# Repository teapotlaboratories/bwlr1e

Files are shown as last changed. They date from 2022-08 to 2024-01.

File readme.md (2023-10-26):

# Teapotlabs BWLR1E
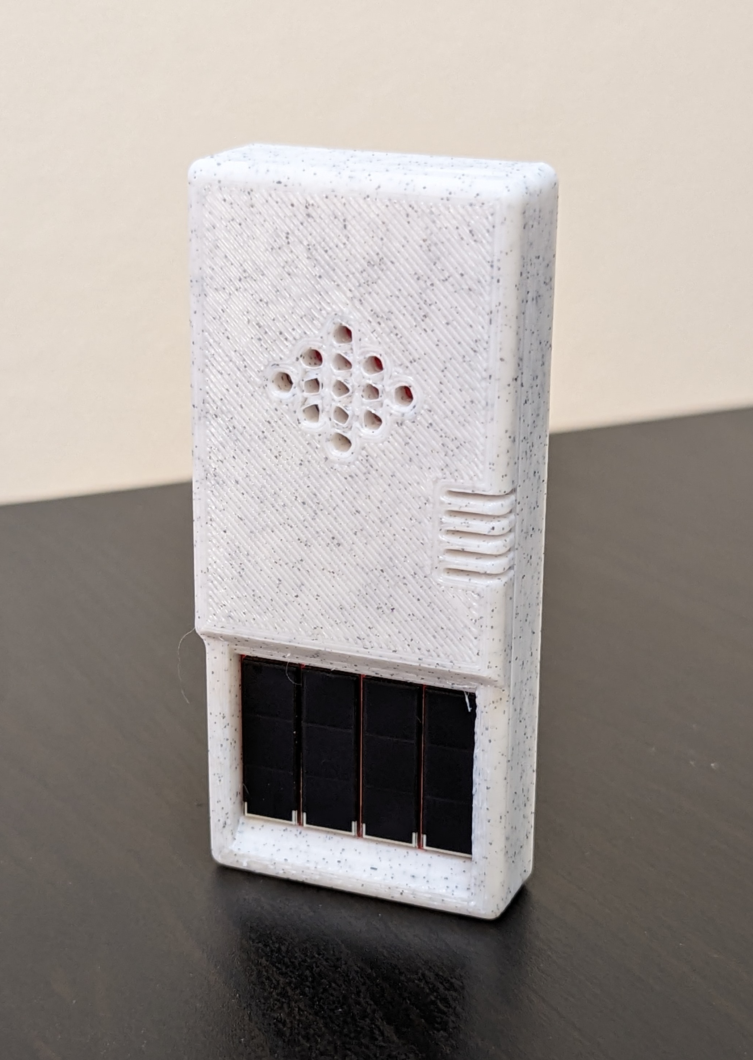
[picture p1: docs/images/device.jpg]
 
 
Teapotlabs BWLR1E is a solar-powered wireless LoRa environmental sensor capable of sensing temperature, humidity, air pressure and air quality using the on-board BME688. 
With STM32WLE MCU as it's core and AEM10941 for solar charging, the device is capable of multi-year operation with the possibility of indefinite battery-life by utilizing the solar charging capability

Teapotlabs BWLR1E is part of  [Teapot open-hardware project](https://github.com/teapotlaboratories). 
  
## Disclaimer
- The 1KM range is based on [AERQ - Air Quality Monitoring](https://www.seeedstudio.com/blog/2022/04/27/monitoring-indoor-air-pollutants-the-silent-issue-for-smart-city-iot-using-seeed-lora-e5-and-fusion-pcba/) design, but have not been tested on this device yet

## Acknowledgement
The project won't be possible without the amazing work from people across the globe. The following are the reference to those awesome projects:

 - [LoRa e5 Tiny](https://github.com/hallard/LoRa-E5-Tiny)
 - [AERQ - Air Quality Monitoring](https://www.seeedstudio.com/blog/2022/04/27/monitoring-indoor-air-pollutants-the-silent-issue-for-smart-city-iot-using-seeed-lora-e5-and-fusion-pcba/)
	 - [Github](https://github.com/Mircerson/AERQ) 
 - [TSEM](https://hackaday.io/project/159139-tiny-solar-energy-module-tsem)

## Specification

- [RAK3172](https://docs.rakwireless.com/Product-Categories/WisDuo/RAK3172-Module/Overview/): An STM32WLE5CC module
- [AEM10941](https://e-peas.com/product/aem10941): Solar energy harvesting
- 3.3V only power/pin. 
- 3uA Deep-Sleep
- BME688 for Environmental Sensing
- Switchable TX Power. 14 dBm(50mA) or 22 dBm(140mA) ( on 915MHz frequency )
- Supports LoRaWAN 1.0.3
- 1KM+ Range
- UART2 breakout for **Arduino/Mbed OS/STM32Cube** programming 
- SWD breakout for debugging and programming
- iPEX antenna connector 
- 3.7 Volts LiPo Battery

## Schematics

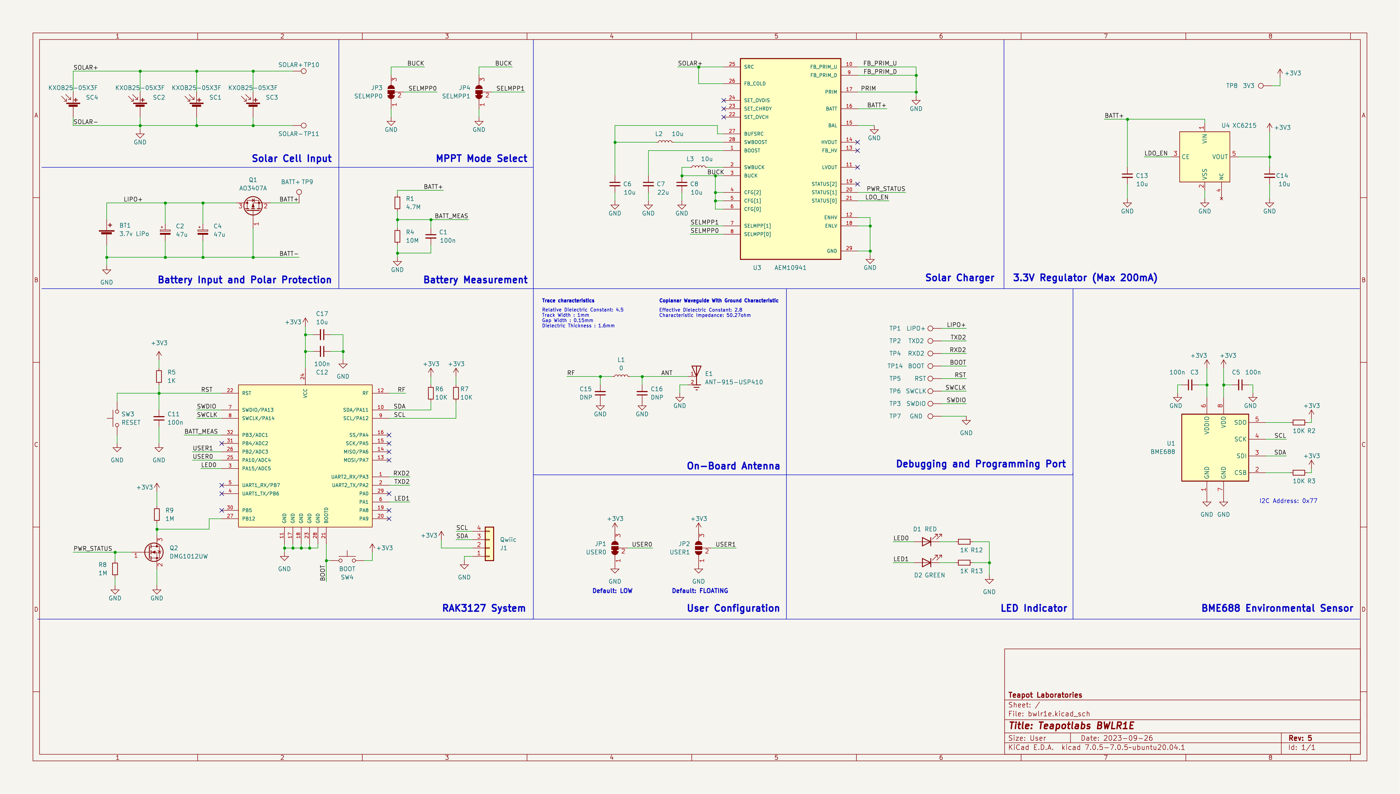
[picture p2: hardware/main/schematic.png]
schematic


## Boards
 <p align="center">  pcb_render<br><b>PCB Render</b></p>

Built using KiCAD, the board is design to be as small as possible with all components placed on the top side of the PCB.
The following are the lists of revision of the board:
- Revision 1: Initial design
- Revision 2: Better trace, use rounded trace and change solar cell wiring to parallel for all cell
- Revision 3: Rename 3V3 to PRIMIN and breaks out PRIMIN
- Revision 4: Improve layout and wiring, and add Qwiic connector
- Revision 5: Change C6 to 22uF

The following design are based on the latest revision.
| Top Board | Bottom Board |
|--|--|
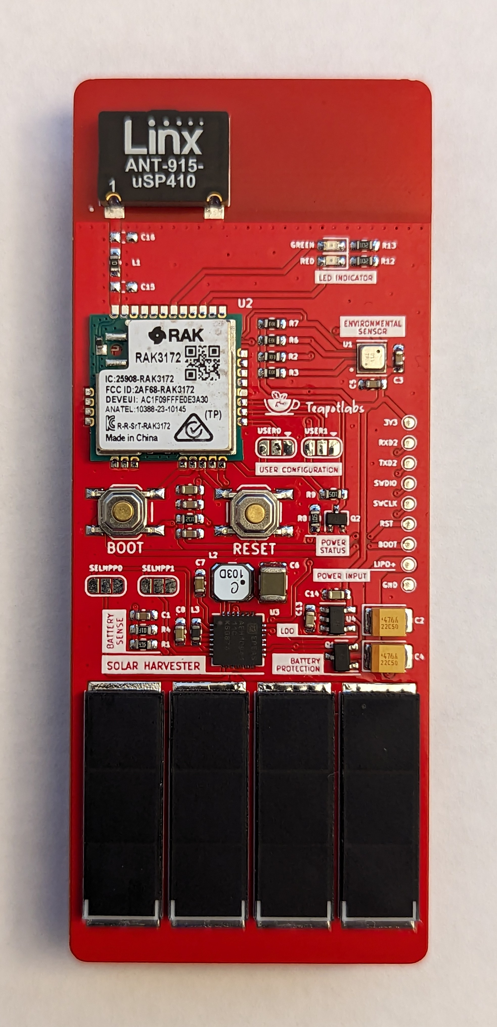
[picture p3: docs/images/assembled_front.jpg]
assembled_front
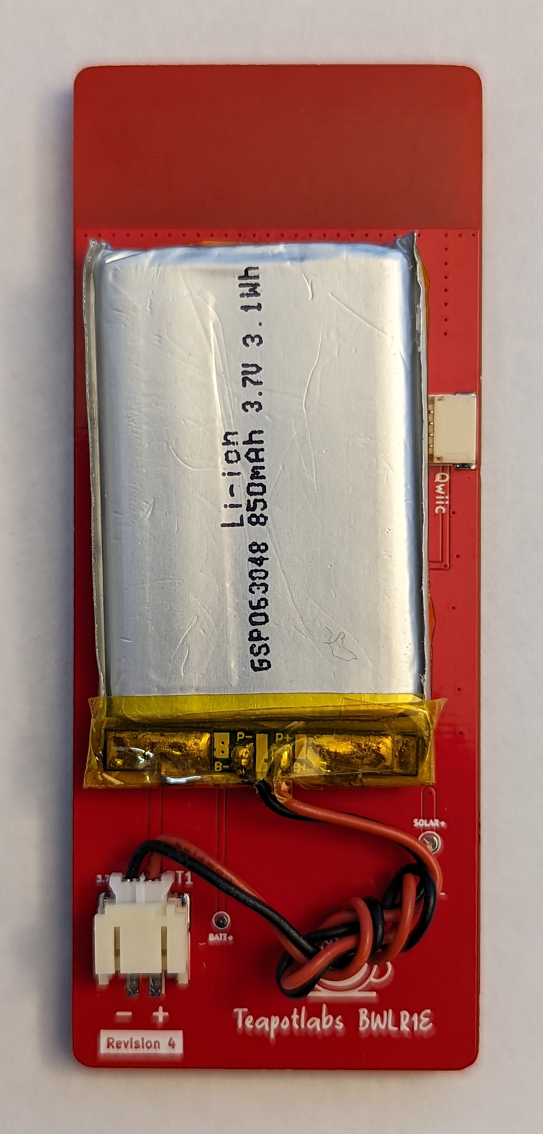
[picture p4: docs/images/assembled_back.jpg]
assembled_back
|  |  |
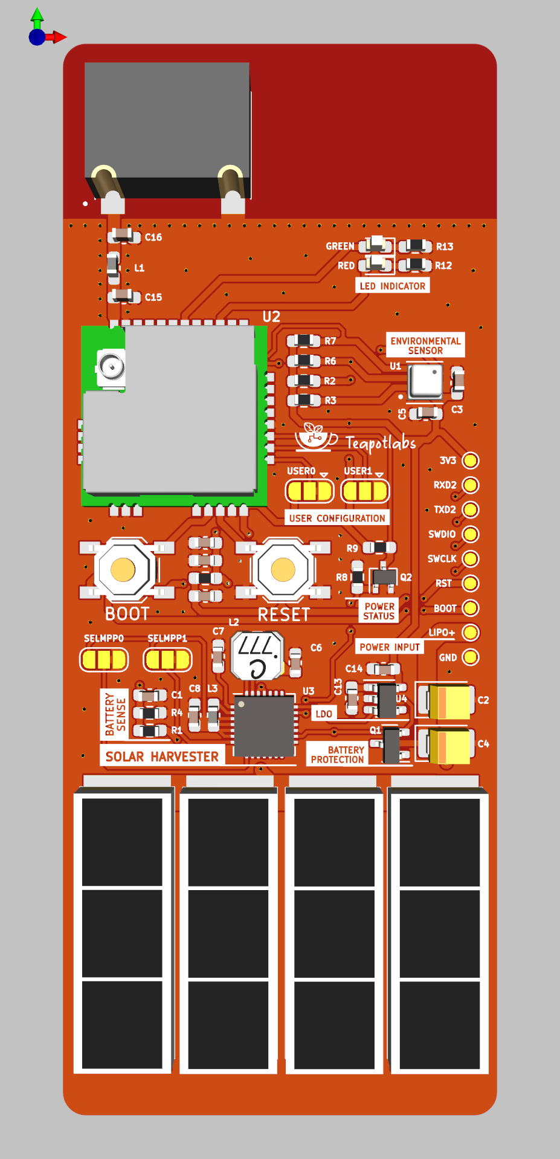
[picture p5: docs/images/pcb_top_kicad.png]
pcb_front
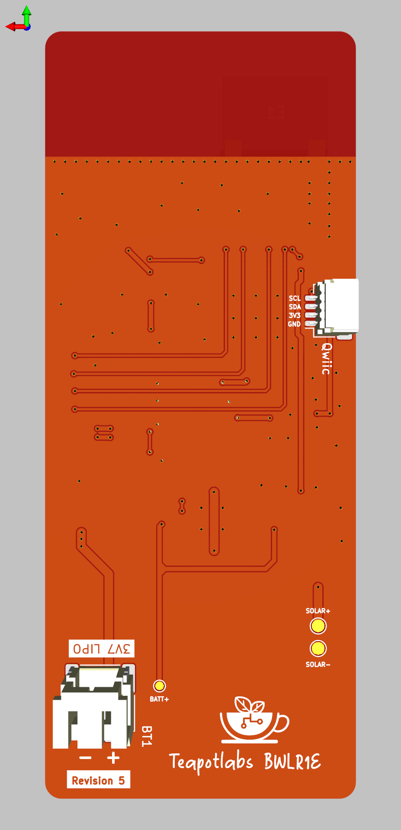
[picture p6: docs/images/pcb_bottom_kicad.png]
pcb_bottom
|  |  |

 <p align="center"> pcb<br><b>PCB Top and Bottom Layout</b></p> 
  
### Case
<p align="center">  case_render</p>

Built using [TinkerCAD](https://www.tinkercad.com). The case are 3D printable with any generic 3D printer with/without support. The STL files are available [here](https://github.com/teapotlaboratories/bwlr1e/tree/main/hardware/main/case)
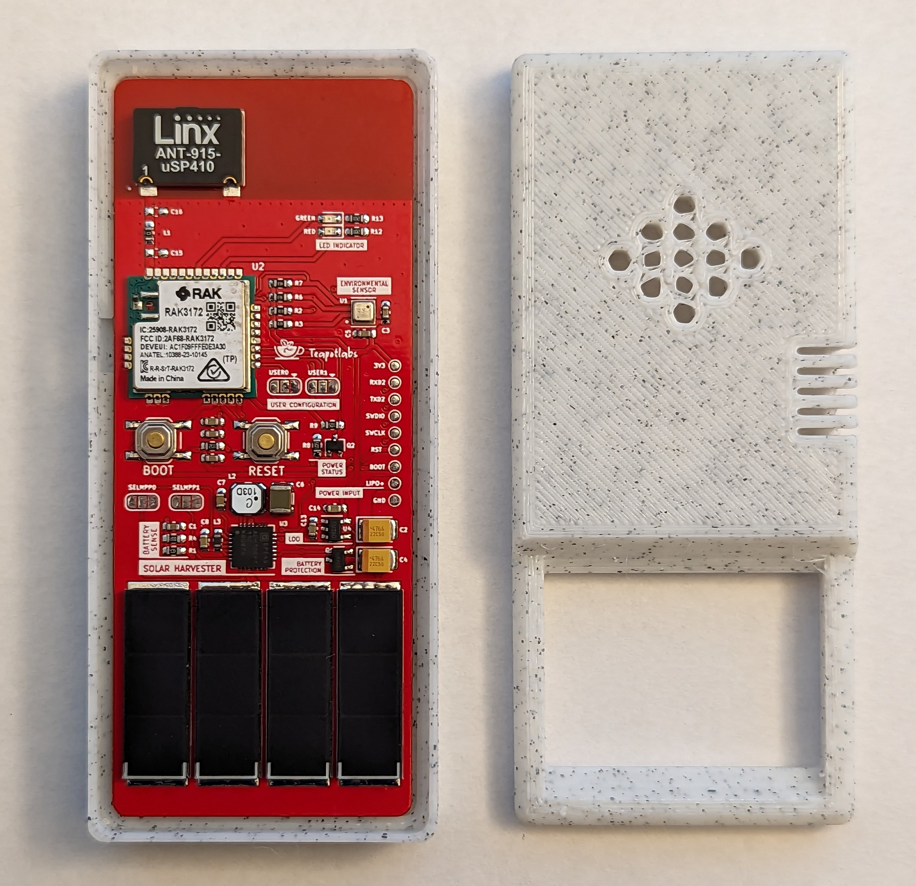
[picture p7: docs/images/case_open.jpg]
 <p align="center"><br><b>Case Open</b></p>

For adding additional sensors, Qwiic connector is also available on the left side of the board.
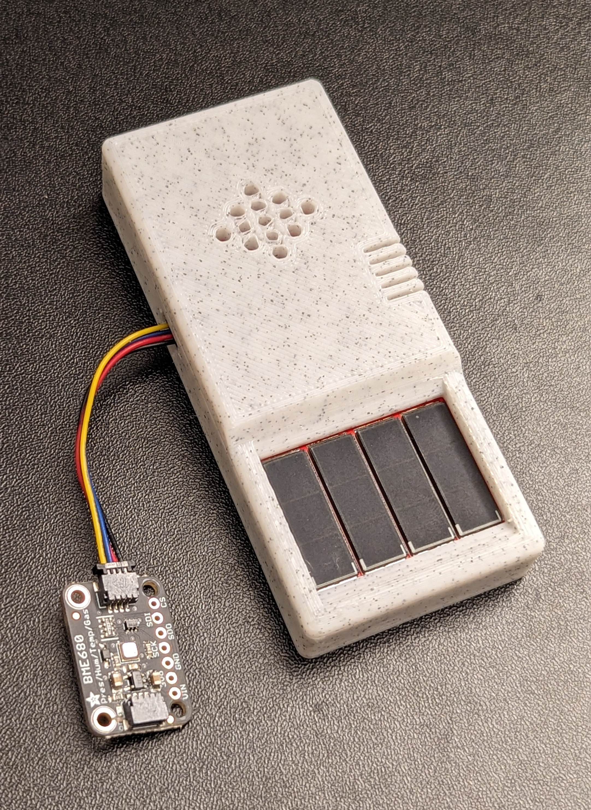
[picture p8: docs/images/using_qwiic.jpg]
 <p align="center"><br><b>Connecting to Adafruit BME688</b></p>

The case is design to be as small as possible with an additional magnets in the back to ease the placement of the sensor. The following are the list of material used at the time of testing:
- 3.7v LiPo Battery, 850mAh 6mm x 30mm x 48mm
- 4 piece of 8mm x 2mm neodymium magnet

<p align="center">placement_showcase<br><b>Sensor Placement with Magnet</b></p>

### Measurement
Power consumption and solar charging current are measured using [Nordic PPK2](https://www.nordicsemi.com/Products/Development-hardware/Power-Profiler-Kit-2)  and [CurrentRanger](https://lowpowerlab.com/shop/product/152).
The following are the summary of the measurement:
- Transmit 14dBm:  305ms @ 20mA
- Deep-Sleep : 3.22 uA
- Direct Sunlight Solar Charge: 9mA
- Indirect Sunlight Solar Charge: 300uA

> :warning: **Tested on Revision 3, but should be similar to Revision 5** 

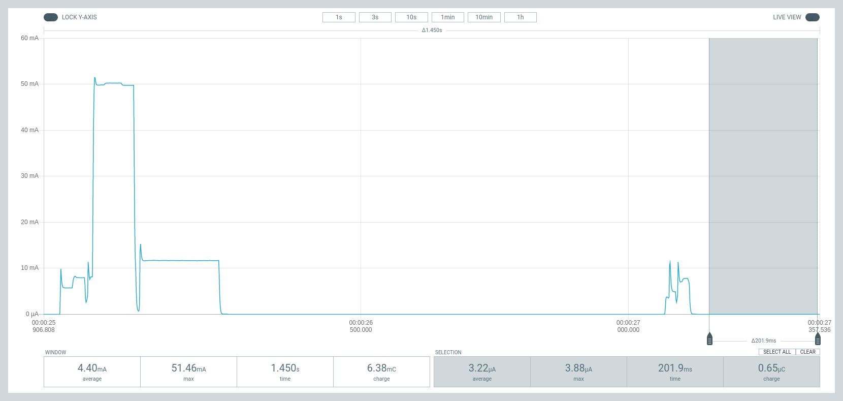
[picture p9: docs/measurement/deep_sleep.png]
deep_sleep
<p align="center"><br><b>Deep-Sleep</b></p>

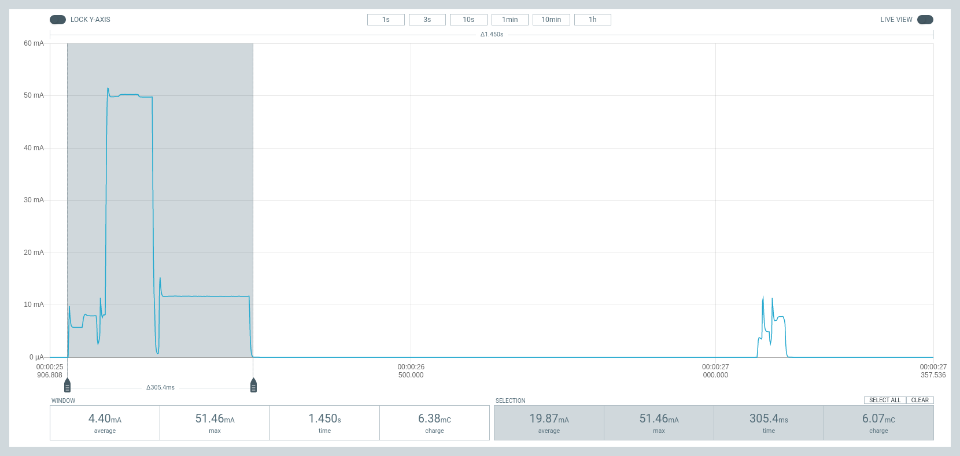
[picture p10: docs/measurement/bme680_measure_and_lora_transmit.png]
bme688_measure_and_lora_transmit
<p align="center"><br><b>BME688 Measure and LoRa Transmit</b></p>

| Solar Charge - Direct Sunlight | Solar Charge - Indirect Sunlight |
|--|--|
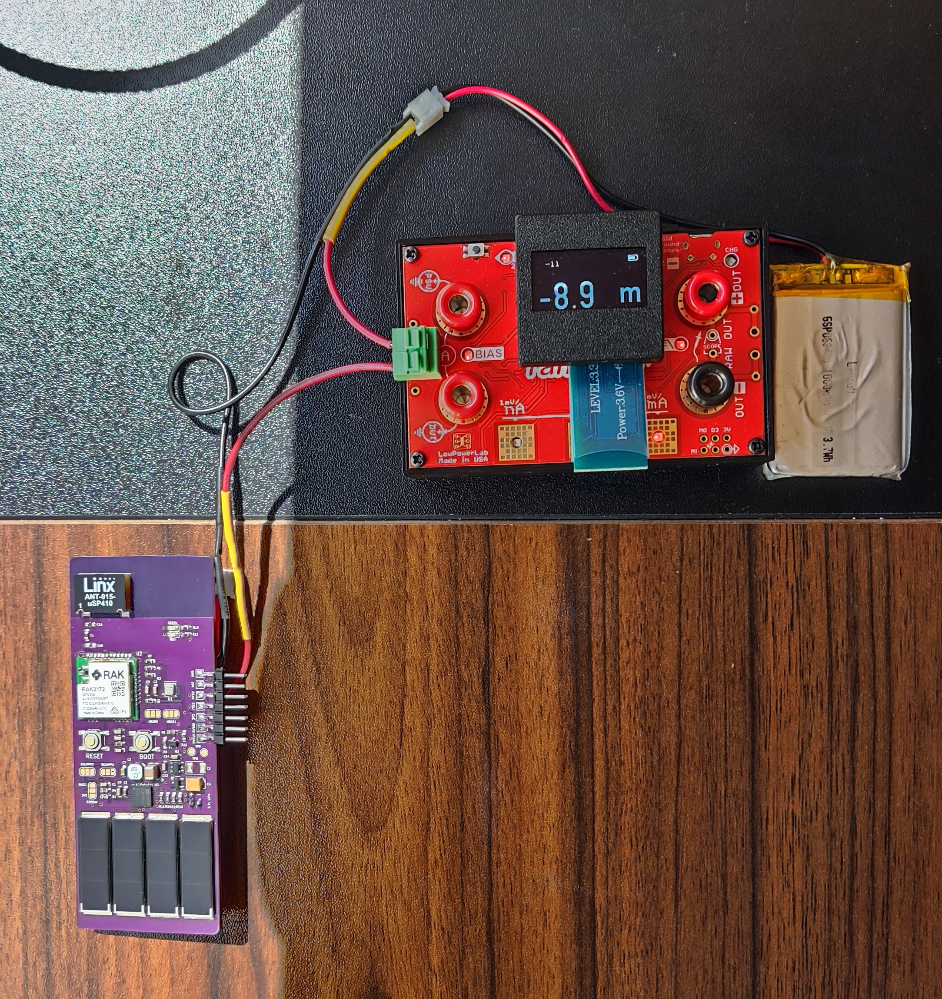
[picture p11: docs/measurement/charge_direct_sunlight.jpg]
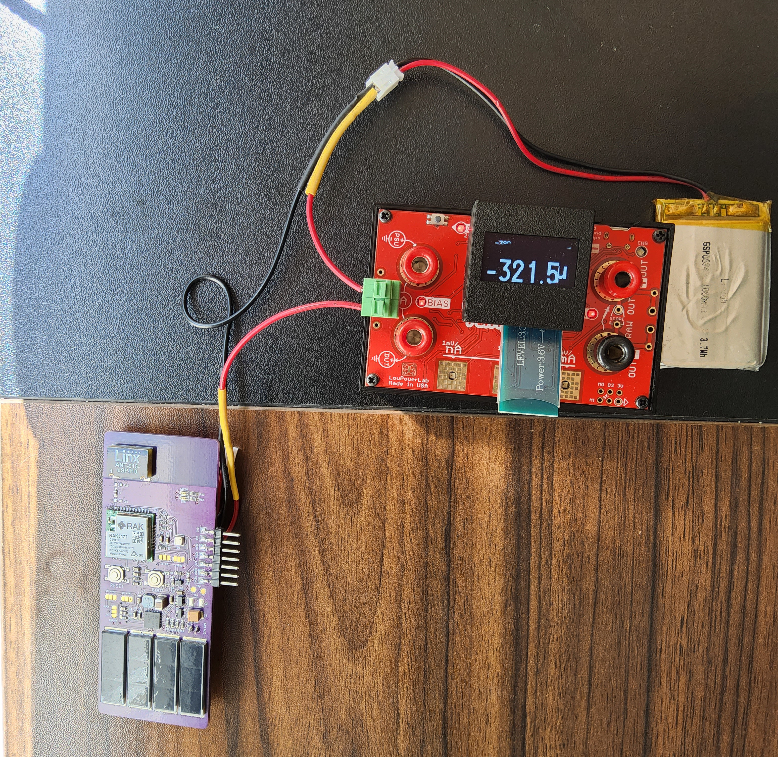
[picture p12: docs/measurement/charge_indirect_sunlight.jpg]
|  |  |

More measurement can be found [here](https://github.com/teapotlaboratories/bwlr1e/tree/main/docs/measurement)

### Bill Of Materials
Most of the components are generic and can be bought from any electornics/semi-conductor distributor. RAK3172 is the only component available in [RAKwireless store](https://store.rakwireless.com/products/wisduo-lpwan-module-rak3172?variant=40014759493830). The bill of materials can be downloaded [here](https://github.com/teapotlaboratories/bwlr1e/blob/main/hardware/main/bill_of_materials.csv)

> :warning: **Be sure to buy the RAK3172 variant without IPEX to use the On-Board Antenna** 

## Programming

> :warning: **Board can only be powered when LiPo battery is connected** 

Programming the device can be done over the **UART2** or **SWD**, available on the right side of the board or uses the [BWLR1E Programmer](https://github.com/teapotlaboratories/bwlr1e/blob/main/readme_programmer.md).
Out of the factory, the RAK3172 chip ships with an **AT firmware** that can be tested by connecting a USB-to-UART bridge to the **UART2** port.

The following are some very good tutorial to start developing with the device:

- [Communicating with the AT firmware](https://docs.rakwireless.com/Product-Categories/WisDuo/RAK3172-Module/Quickstart/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)
 - [Programming with Arduino](https://docs.rakwireless.com/Product-Categories/WisDuo/RAK3172-Module/Quickstart/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)
 - [Programming with STM32Cube](https://docs.rakwireless.com/Product-Categories/WisDuo/RAK3172-Module/Low-Level-Development/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)
 - [Programming with MbedOS](https://github.com/hallard/LoRa-E5-Tiny/blob/main/README.md#compile-and-flash-firmware)

For connecting to the **UART2** port, use any USB-to-UART bridge module. In testing, the [Sparkfun](https://www.sparkfun.com/products/14050) board is used for communication with AT firmware and programming over **Arduino**.
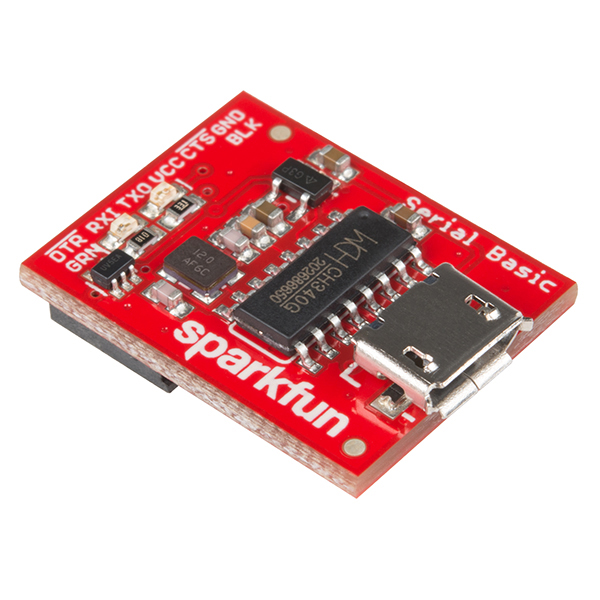
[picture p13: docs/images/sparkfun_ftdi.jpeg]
 <p align="center"> <br>Sparkfun USB-to-UART Bridge</p>

> :warning: **Be sure to only use 3.3V module. Do not 5V module** 

### Available SDK
Through **UART2**, user can program the device using the following SDK:
- [Arduino RUI3 SDK](https://github.com/RAKWireless/RAKwireless-Arduino-BSP-Index)
- [Arduino STM32duino SDK](https://github.com/stm32duino/Arduino_Core_STM32)
- [MbedOS](https://github.com/hallard/LoRa-E5-Tiny/blob/main/README.md#compile-and-flash-firmware)
- [STM32Cube](https://docs.rakwireless.com/Product-Categories/WisDuo/RAK3172-Module/Low-Level-Development/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)

Other than [Arduino RUI3 SDK](https://github.com/RAKWireless/RAKwireless-Arduino-BSP-Index), to program the device, user need to put the device in Serial Bootloader mode by,
1. Press and Hold `BOOT` and `RESET` button
2. Release `RESET` button 
3. Wait few seconds ( try 2 seconds )
4. Release `BOOT` button
5. Device should be in Serial Bootloader mode.

You can also use [STM32CubeProgrammer](https://www.st.com/en/development-tools/stm32cubeprog.html) , instead of the SDK  to upload a firmware
  
### Programming with Teapotlabs BWLR1E Programmer
 <p align="center"> <br>Teapotlabs BWLR1E Programmer</p>

An alternative to solder-free programming is to use the Teapotlabs BWLR1E Programmer. A full detail of the device can be found [here](https://github.com/teapotlaboratories/bwlr1e/blob/main/readme_programmer.md).
The programmer connects to UART2 of the device. 

## License
The product is open-source! However, some part of library used under **src**, might have it's own license.
Please reach out or create a ticket to report any license violation.



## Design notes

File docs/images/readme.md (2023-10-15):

# Documentation Images

## Assembled Front and Back


## Case Close
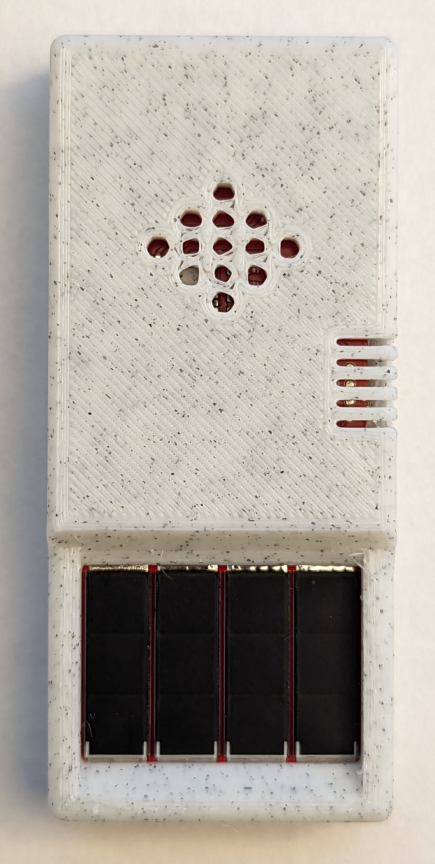
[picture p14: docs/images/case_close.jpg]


## Case Open


## Case Render


## Device


## Device Close-up
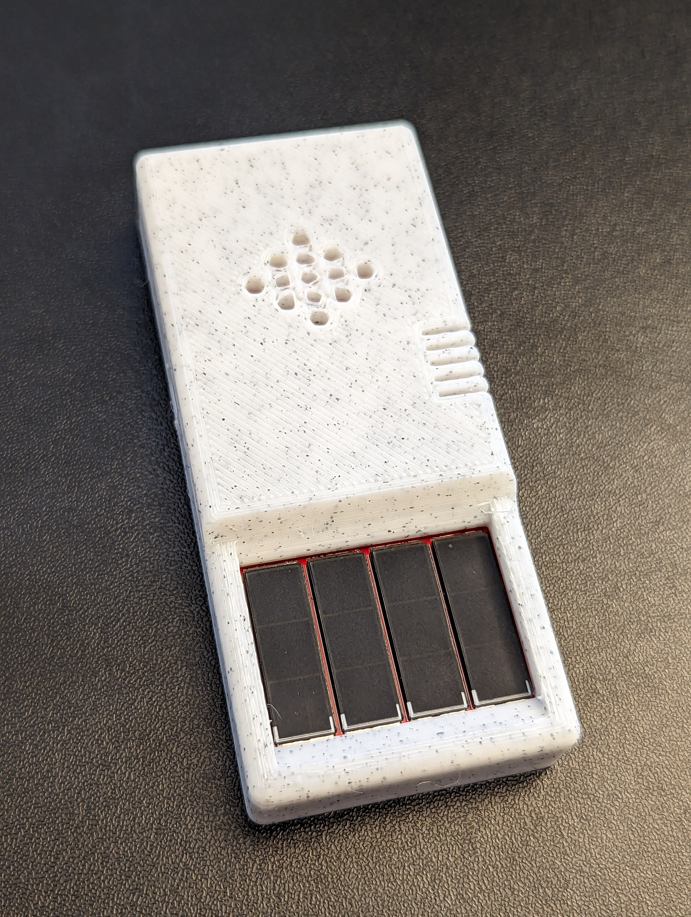
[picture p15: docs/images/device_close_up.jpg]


## PCB Render


## PCB Bottom
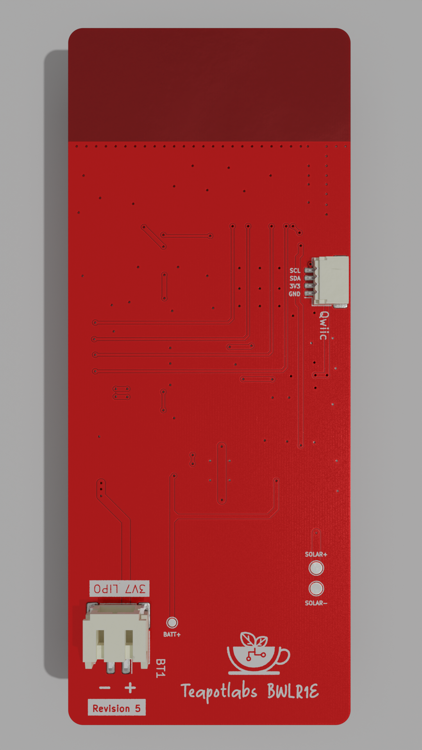
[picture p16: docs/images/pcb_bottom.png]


## PCB Top
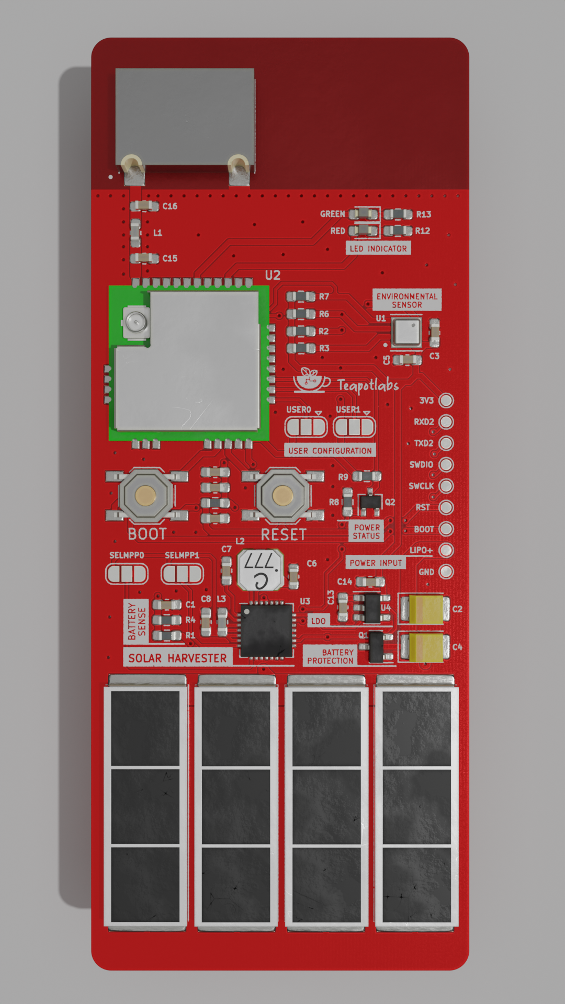
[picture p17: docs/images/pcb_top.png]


## Case Open


## Case Open


## Placement Showcase


## AA Battery for Comparison
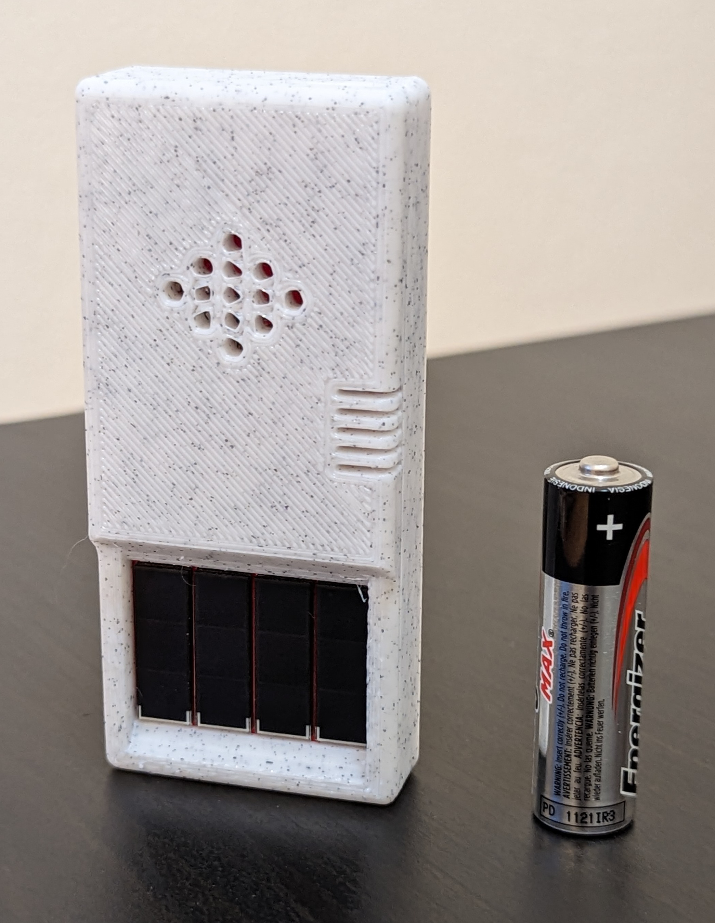
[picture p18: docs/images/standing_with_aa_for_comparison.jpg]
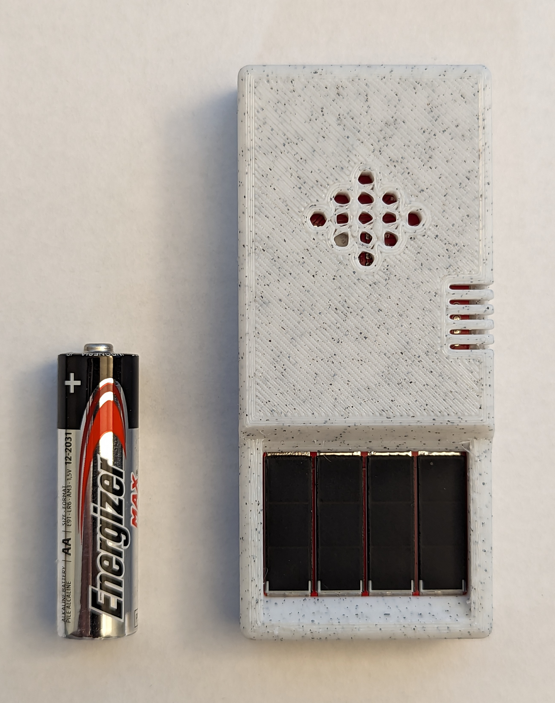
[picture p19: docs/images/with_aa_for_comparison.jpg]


## Using Qwiic Connector


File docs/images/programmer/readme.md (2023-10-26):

# Documentation Images

## Assembled Front and Back
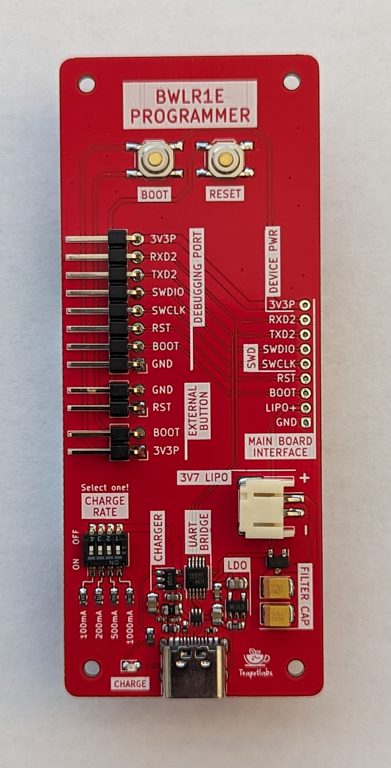
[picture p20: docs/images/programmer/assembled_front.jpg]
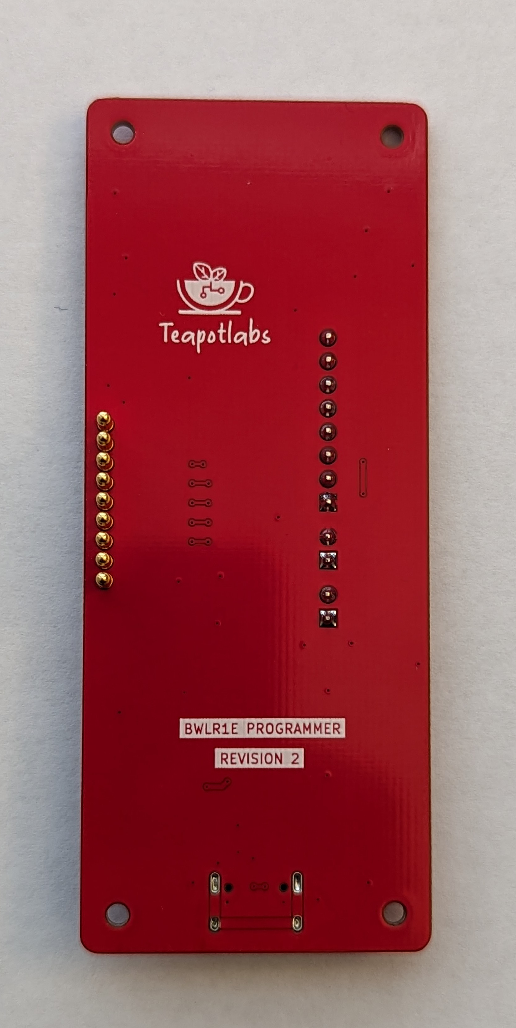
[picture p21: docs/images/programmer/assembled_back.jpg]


## Case Close
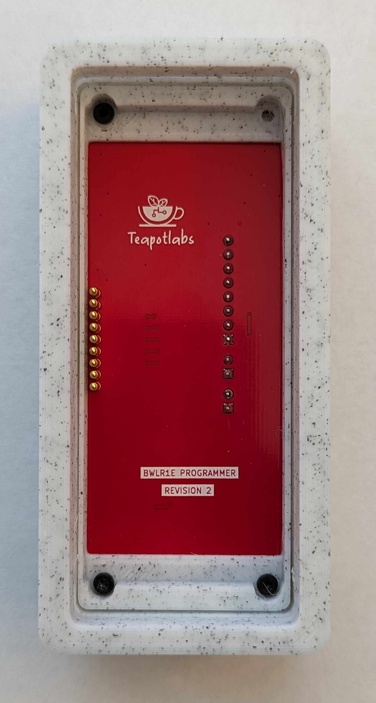
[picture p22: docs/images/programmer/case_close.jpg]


## Case Open
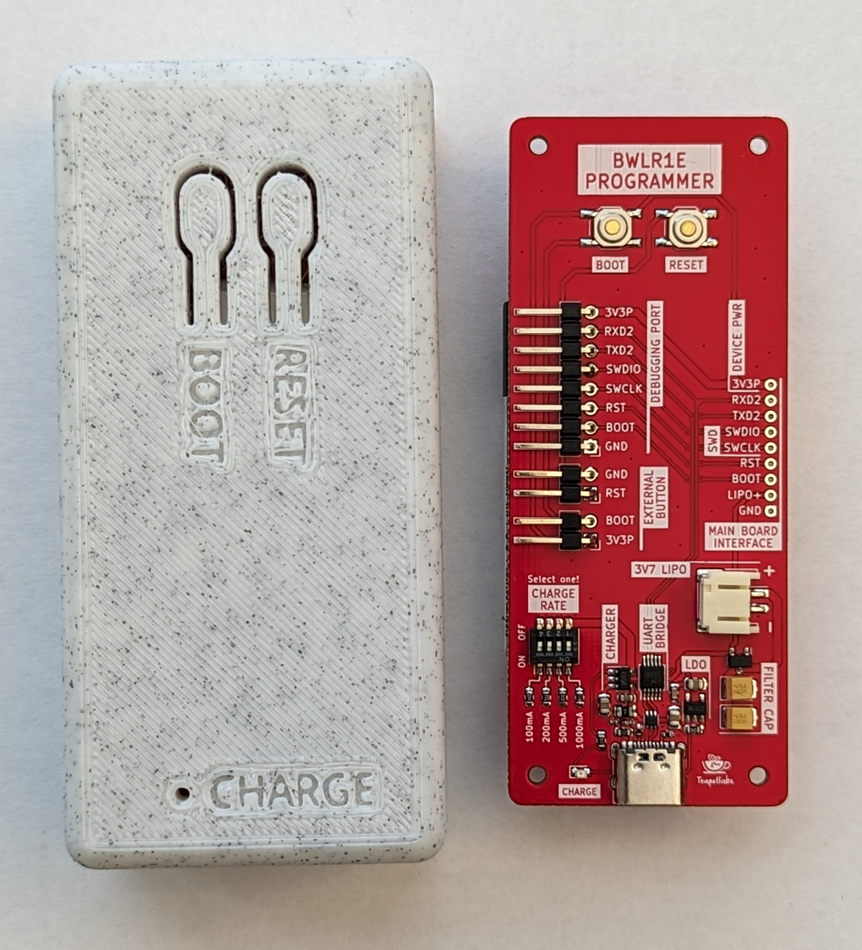
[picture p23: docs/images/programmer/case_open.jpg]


## Case Render


## Device
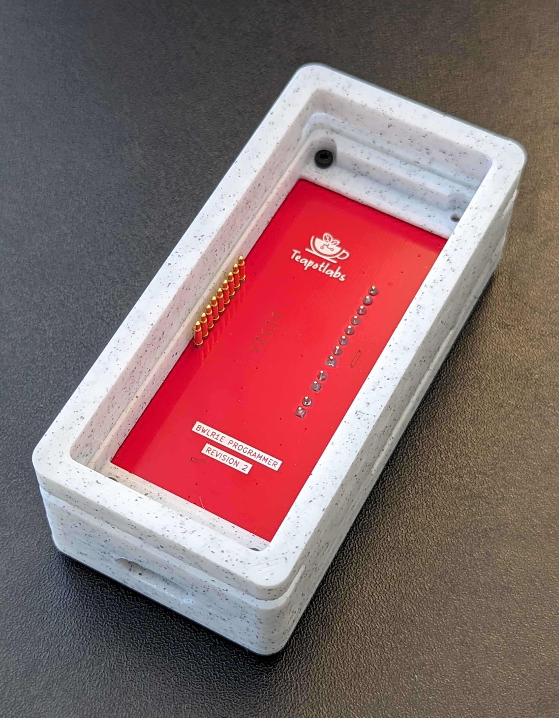
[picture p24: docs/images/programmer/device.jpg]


## PCB Render


## PCB Bottom
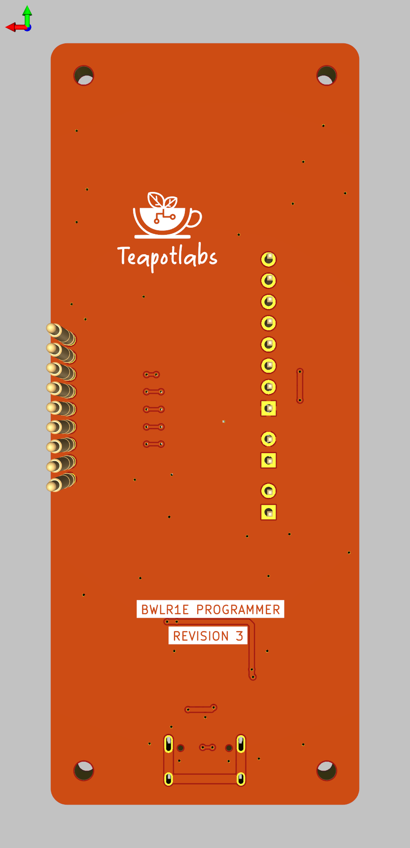
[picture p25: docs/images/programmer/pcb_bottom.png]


## PCB Top
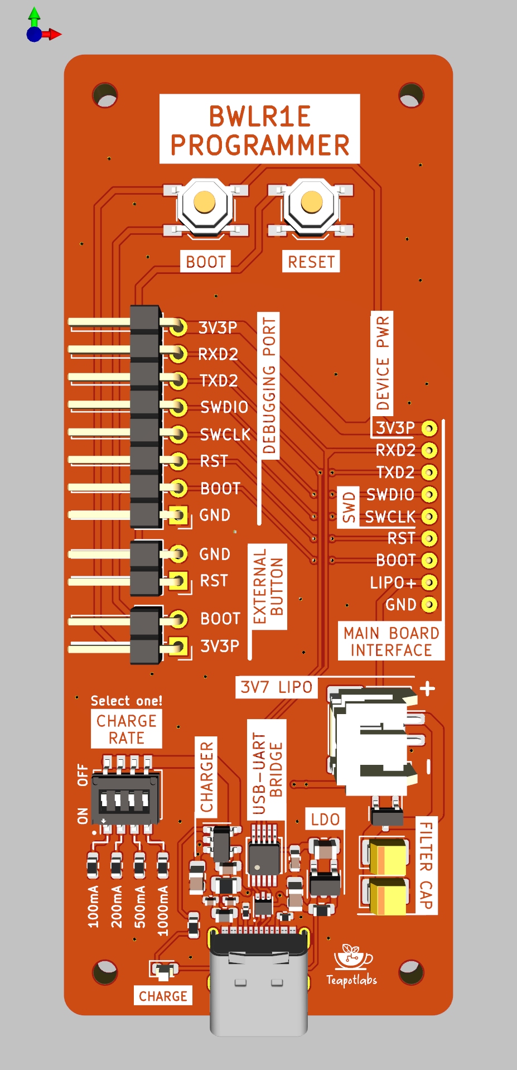
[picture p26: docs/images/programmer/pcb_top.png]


## Programming BWLR1E


## Showcase Render Exploded View
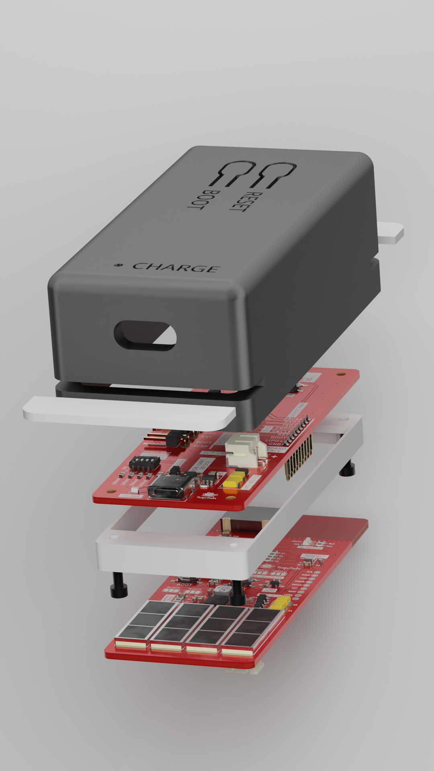
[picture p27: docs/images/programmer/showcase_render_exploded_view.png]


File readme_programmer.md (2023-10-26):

# Teapotlabs BWLR1E Programmer	

<p align="center">  case_render</p>
 
Teapotlabs BWLR1E Programmer is a device to support programming Teapotlabs BWLR1E without soldering to the device. The programmer interface to the device program pad via pogo-pins.
 
## Specification

- CH340E USB to UART Bridge for Teapotlabs BWLR1E Programming
- 1A Charge rate to Teapotlabs BWLR1E battery
- Pogo-pin to interface to Teapotlabs BWLR1E. Connects the following pin:
	- RXD2
	- TXD2
	- SWDIO
	- SWCLK
	- RST
	- BOOT
	- LIPO+
- On-board `boot` and `reset` button
- Pin header for external button

## Schematics

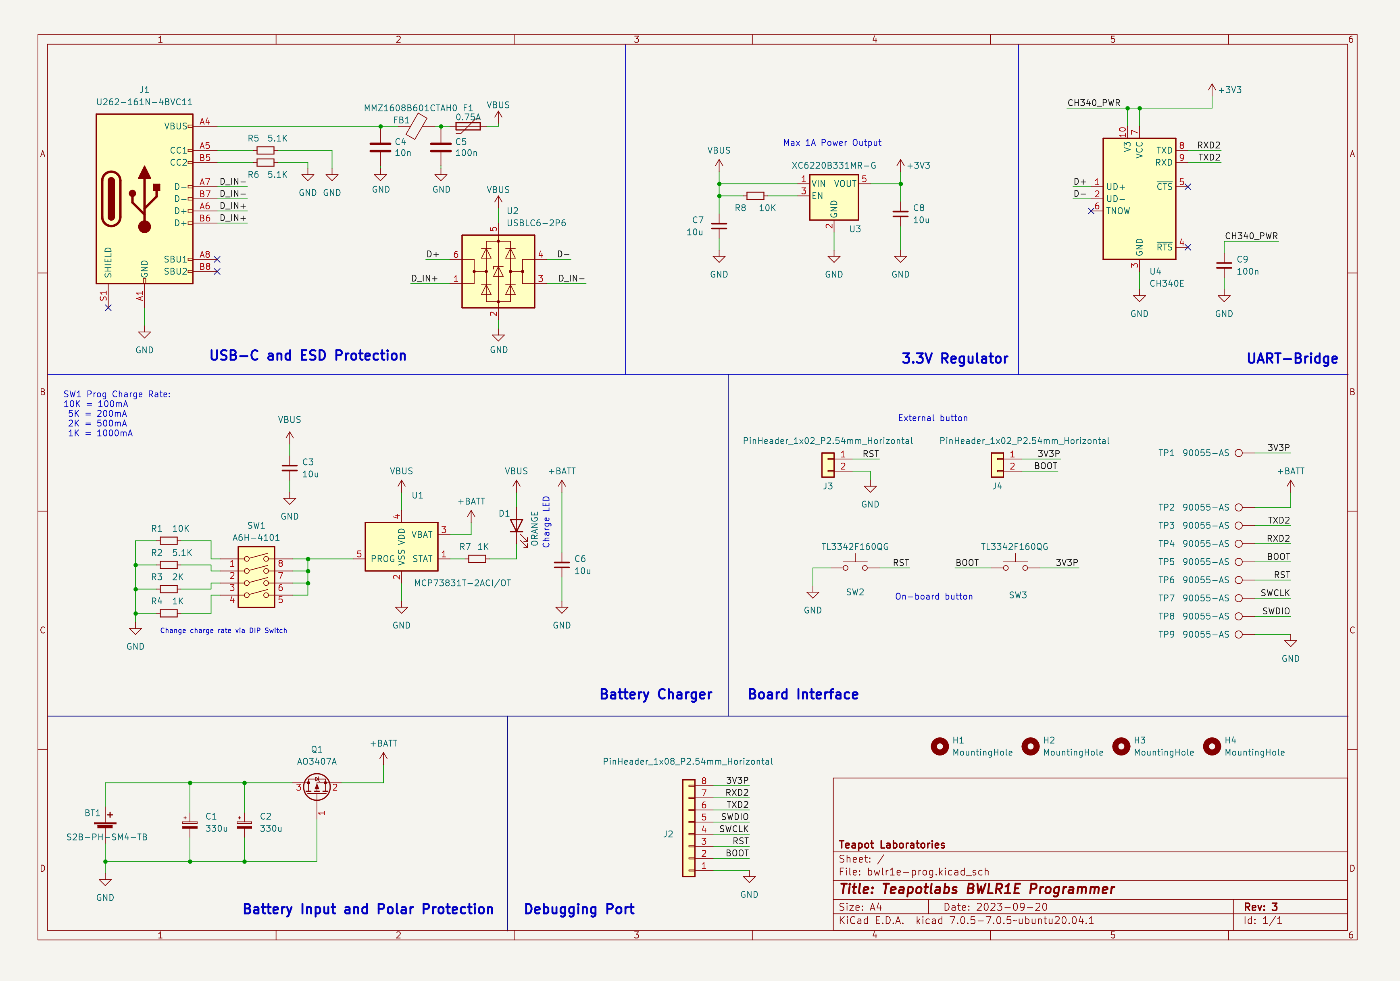
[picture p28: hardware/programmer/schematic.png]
schematic


## Boards
 <p align="center">  pcb_render<br><b>PCB Render</b></p>

Built using KiCAD v7, the board is design to connect to the programming and charge pad of Teapotlabs BWLR1E via pogo-pins connector

The following design are based on the latest revision.
| Top Board | Bottom Board |
|--|--|
| <p align="center"> assembled_front</p> | <p align="center"> assembled_back</p> |
| <p align="center"> pcb_front</p> | <p align="center"> pcb_bottom</p> |

 <p align="center"> pcb<br><b>PCB Top and Bottom Layout</b></p> 
  
### Case
 <p align="center"> <br>Teapotlabs BWLR1E Programmer Exploded View</p>

Built using [TinkerCAD](https://www.tinkercad.com). The case are 3D printable with any generic 3D printer with/without support. The STL files are available [here](https://github.com/teapotlaboratories/bwlr1e/tree/main/hardware/programmer/case)
The case is made of 3 parts:
- Main case: holds the Programmer.
- Separator: separate the programmer and Teapotlabs BWLR1E.
- Locks: locks Teapotlabs BWLR1E in place for charging the device.
 <p align="center"><br><b>Case Open</b></p>

### Bill Of Materials
Most of the components are generic and can be bought from any electornics/semi-conductor distributor. The bill of materials can be downloaded [here](https://github.com/teapotlaboratories/bwlr1e/blob/main/hardware/programmer/bill_of_materials.csv)

## Programming Teapotlabs BWLR1E

 <p align="center"> <br>Setting-up Teapotlabs BWLR1E Programmer</p>
 
Using the programmer, Teapotlabs BWLR1E can be programmed via the USB-C available in the programmer.
Out of the factory, the Teapotlabs BWLR1E chip ships with an **AT firmware** that can be tested by sending AT commands using the programmer USB-C.

The following are some very good tutorial to start developing with the device:

- [Communicating with the AT firmware](https://docs.rakwireless.com/Product-Categories/WisDuo/RAK3172-Module/Quickstart/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)
 - [Programming with Arduino](https://docs.rakwireless.com/Product-Categories/WisDuo/RAK3172-Module/Quickstart/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)
 - [Programming with STM32Cube](https://docs.rakwireless.com/Product-Categories/WisDuo/RAK3172-Module/Low-Level-Development/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)
 - [Programming with MbedOS](https://github.com/hallard/LoRa-E5-Tiny/blob/main/README.md#compile-and-flash-firmware)

### Available SDK
Through the USB-C, user can program Teapotlabs BWLR1E using the following SDK:

-   [Arduino RUI3 SDK](https://github.com/RAKWireless/RAKwireless-Arduino-BSP-Index)
-   [Arduino STM32duino SDK](https://github.com/stm32duino/Arduino_Core_STM32)
-   [MbedOS](https://github.com/hallard/LoRa-E5-Tiny/blob/main/README.md#compile-and-flash-firmware)
-   [STM32Cube](https://docs.rakwireless.com/Product-Categories/WisDuo/RAK3172-Module/Low-Level-Development/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)

Other than  [Arduino RUI3 SDK](https://github.com/RAKWireless/RAKwireless-Arduino-BSP-Index), to program the device, user need to put the device in Serial Bootloader mode by,

1.  Press and Hold  `BOOT`  and  `RESET`  button
2.  Release  `RESET`  button
3.  Wait few seconds ( try 2 seconds )
4.  Release  `BOOT`  button
5.  Device should be in Serial Bootloader mode.

You can also use  [STM32CubeProgrammer](https://www.st.com/en/development-tools/stm32cubeprog.html)  , instead of the SDK to upload a firmware

## License
The product is open-source! However, some part of library used under **src**, might have it's own license.
Please reach out or create a ticket to report any license violation.



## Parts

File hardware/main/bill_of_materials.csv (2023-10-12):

Id | Designator | Quantity | Manufacturer | Manufacturer Part Number | Value | Description | Footprint | Type | Distributor | Distributor Part Number | Distributor Link
1 | BT1 | 1 | JST | S2B-PH-SM4-TB | 3.7v LiPo | Connector Header Right Angle 2 position 0.079" (2.00mm) | JST_PH_S2B-PH-SM4-TB | SMD | LCSC | C295747 | https://www.lcsc.com/product-detail/Wire-To-Board-Wire-To-Wire-Connector_JST-Sales-America-S2B-PH-SM4-TB-LF-SN_C295747.html
2 | C1, C3, C5, C11, C12 | 5 | YAGEO | CC0603KRX7R6BB104 | 100n | Ceramic Capacitor 100nF 10% 10V X7R | C_0603_1608Metric | SMD | LCSC | C519438 | https://www.lcsc.com/product-detail/Multilayer-Ceramic-Capacitors-MLCC-SMD-SMT_YAGEO-CC0603KRX7R6BB104_C519438.html
3 | C2, C4 | 2 | KYOCERA AVX | TPSB476K010R0350 | 47u | Tantalum Capacitors 47µF 10% 10 V 250mOhm | EIA-3528-15 | SMD | Digikey | 478-9088-1-ND | https://www.digikey.com/en/products/detail/kyocera-avx/TPSB476K010R0350/1472821
4 | C7 | 1 | Murata Electronics | GRM188R61A226ME15D | 22u | Ceramic Capacitor 22uF 20% 10V X5R | C_0603_1608Metric | SMD | LCSC | C84419 | https://www.lcsc.com/product-detail/Multilayer-Ceramic-Capacitors-MLCC-SMD-SMT_Murata-Electronics-GRM188R61A226ME15D_C84419.html
5 | C6, C8, C13, C14, C17 | 5 | Murata Electronics | GRT188R61A106KE13D | 10u | Ceramic Capacitor 10uF 10% 10V X5R | C_0603_1608Metric | SMD | LCSC | C782172 | https://www.lcsc.com/product-detail/Multilayer-Ceramic-Capacitors-MLCC-SMD-SMT_Murata-Electronics-GRT188R61A106KE13D_C782172.html
6 | D1 | 1 | Lite-On | LTST-C191KRKT | RED | Red 2V 20mA | LED_0603_1608Metric | SMD | LCSC | C125099 | https://www.lcsc.com/product-detail/Light-Emitting-Diodes-LED_Lite-On-LTST-C191KRKT_C125099.html
7 | D2 | 1 | Lite-On | LTST-C190KGKT | GREEN | Green 2V 20mA | LED_0603_1608Metric | SMD | LCSC | C125094 | https://www.lcsc.com/product-detail/Light-Emitting-Diodes-LED_Lite-On-LTST-C190KGKT_C125094.html
8 | E1 | 1 | Linx Technologies Inc. | ANT-915-USP410 | ANT-915-USP410 | Chip RF Antenna 902MHz ~ 930MHz 0.9dBi Solder Surface Mount | ANT-915-USP410 | SMD | Digikey | 343-ANT-915-USP410CT-ND | https://www.digikey.com/en/products/detail/linx-technologies-inc/ANT-915-USP410/13165344
9 | J1 | 1 | JST | SM04B-SRSS-TB | Qwiic | Connector Header Right Angle 4 position 0.039" (1.00mm) | JST_SH_SM04B-SRSS-TB | SMD | LCSC | C160404 | https://www.lcsc.com/product-detail/Wire-To-Board-Wire-To-Wire-Connector_JST-Sales-America-SM04B-SRSS-TB-LF-SN_C160404.html
10 | L1 | 1 | UNI-ROYAL(Uniroyal Elec) | 0603WAF0000T5E | 0 | Resistor 0 5% 100mW | L_0603_1608Metric | SMD | LCSC | C21189 | https://www.lcsc.com/product-detail/Chip-Resistor-Surface-Mount_UNI-ROYAL-Uniroyal-Elec-0603WAF0000T5E_C21189.html
11 | L2 | 1 | Coilcraft | LPS4012-103MRC | 10u | Power Inductor 10uH 20% 1.1A | IND_LPS4012-103MRB | SMD | Mouser | 994-LPS4012-103MRC | https://www.mouser.com/ProductDetail/994-LPS4012-103MRC
12 | L3 | 1 | TDK | MLZ1608M100WT000 | 10u | Power Inductor 10uH 20% 90mA | L_0603_1608Metric | SMD | LCSC | C76798 | https://www.lcsc.com/product-detail/Inductors-SMD_TDK-MLZ1608M100WT000_C76798.html
13 | Q1 | 1 | Alpha & Omega Semicon | AO3407A | AO3407A | P-Channel Enhacnement Mode MOSFET 30V 4.3A 48mΩ@10V | SOT-23 | SMD | LCSC | C15155 | https://www.lcsc.com/product-detail/MOSFETs_Alpha-Omega-Semicon-AO3407A_C15155.html
14 | Q2 | 1 | TECH PUBLIC | DMG1012UW | DMG1012UW | N-Channel Enhancement Mode MOSFET 20V 0.9A 300mΩ@2.5V | SOT-323_SC-70 | SMD | LCSC | C2940609 | https://www.lcsc.com/product-detail/MOSFETs_TECH-PUBLIC-DMG1012UW_C2940609.html
15 | R1 | 1 | UNI-ROYAL(Uniroyal Elec) | 0603WAF4704T5E | 4.7M | Resistor 4.7M 1% 100mW | R_0603_1608Metric | SMD | LCSC | C23163 | https://www.lcsc.com/product-detail/Chip-span-style-background-color-ff0-Resistor-span-Surface-Mount_UNI-ROYAL-Uniroyal-Elec-0603WAF4704T5E_C23163.html
16 | R2, R3, R6, R7 | 4 | YAGEO | RC0603JR-0710KL | 10K | Resistor 10K 5% 100mW | R_0603_1608Metric | SMD | LCSC | C99198 | https://www.lcsc.com/product-detail/_YAGEO-_C99198.html
17 | R4 | 1 | UNI-ROYAL(Uniroyal Elec) | 0603WAF1005T5E | 10M | Resistor 10M 1% 100mW | R_0603_1608Metric | SMD | LCSC | C7250 | https://www.lcsc.com/product-detail/Chip-span-style-background-color-ff0-Resistor-span-Surface-Mount_UNI-ROYAL-Uniroyal-Elec-0603WAF1005T5E_C7250.html
18 | R5, R12, R13 | 3 | FOJAN | FRC0603J102TS | 1K | Resistor 1K 5% 100mW | R_0603_1608Metric | SMD | LCSC | C2907113 | https://www.lcsc.com/product-detail/_FOJAN-_C2907113.html
19 | R8, R9 | 2 | UNI-ROYAL(Uniroyal Elec) | 0603WAJ0105T5E | 1M | Resistor 1M 5% 100mW | R_0603_1608Metric | SMD | LCSC | C26098 | https://www.lcsc.com/product-detail/Chip-span-style-background-color-ff0-Resistor-span-Surface-Mount_UNI-ROYAL-Uniroyal-Elec-0603WAJ0105T5E_C26098.html
20 | SC1, SC2, SC3, SC4 | 4 | ANYSOLAR Ltd | KXOB25-05X3F | KXOB25-05X3F | Monocrystalline Solar Cell 30.7 mW 2.07 V | KXOB25-05X3F | SMD | Digikey | KXOB25-05X3FCT-ND | https://www.digikey.com/en/products/detail/anysolar-ltd/KXOB25-05X3F-TR/9990478
21 | SW3 | 1 | E-Switch | TL3342F160QG | RESET | SPST SMD Tactile Switches | SW_SPST_TL3342 | SMD | LCSC | C2886898 | https://www.lcsc.com/product-detail/Tactile-Switches_E-Switch-TL3342F160QG_C2886898.html
22 | SW4 | 1 | E-Switch | TL3342F160QG | BOOT | SPST SMD Tactile Switches | SW_SPST_TL3342 | SMD | LCSC | C2886898 | https://www.lcsc.com/product-detail/Tactile-Switches_E-Switch-TL3342F160QG_C2886898.html
23 | U1 | 1 | Bosch Sensortec | BME688 | BME688 | Air Quality Sensors Combined gas, humidity, pressure and temperature sensor | BME688 | SMD | Mouser | 262-BME688 | https://www.mouser.com/ProductDetail/Bosch-Sensortec/BME688?qs=IS%252B4QmGtzzqQoVDscqwx3A%3D%3D
24 | U2 | 1 | RAKwireless | 309054 | RAK3172-T | RAK3172-T Module with TCXO, without IPEX, Frequency 915MHz, Band AS923 | RAK3172 | SMD | RAKwireless | 309054 | Contact inquiry@rakwireless.com for SKU: 309054
25 | U3 | 1 | e-peas | AEM10941-QFN | AEM10941 | Photovoltaic Energy Harvesting Manager | QFN-28-1EP_5x5mm_P0.5mm_EP3.35x3.35mm | SMD | Mouser | 120-AEM10941-QFN | https://www.mouser.com/ProductDetail/e-peas/AEM10941-QFN?qs=W%2FMpXkg%252BdQ7CeqB2lBPbRQ%3D%3D
26 | U4 | 1 | Torex Semicon | XC6215B332MR-G | XC6215 | Linear Voltage Regulators (LDO) 200mA Fixed +3.3V | SOT-23-5 | SMD | LCSC | C98230 | https://www.lcsc.com/product-detail/Linear-Voltage-Regulators-LDO_Torex-Semicon-XC6215B332MR-G_C98230.html
27 | C15, C16 | 0 | - | - | DNP | Do Not Populate | - | DNP | - | - | -

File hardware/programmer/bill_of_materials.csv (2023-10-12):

Id | Designator | Quantity | Manufacturer | Manufacturer Part Number | Value | Description | Footprint | Type | Distributor | Distributor Part Number | Distributor Link
1 | BT1 | 1 | JST | S2B-PH-SM4-TB(LF)(SN) | S2B-PH-SM4-TB(LF)(SN) | Connector Header Right Angle 2 position 0.079" (2.00mm) | JST_PH_S2B-PH-SM4-TB | SMD | LCSC | C295747 | https://www.lcsc.com/product-detail/Wire-To-Board-Wire-To-Wire-Connector_JST-Sales-America-S2B-PH-SM4-TB-LF-SN_C295747.html
2 | C1, C2 | 2 | KEMET | T520B337M006ATE040 | 330u | Tantalum Capacitors 330µF 20% 6.3 V 40mOhm | CP_EIA-3528-15_AVX-H | SMD | LCSC | C696806 | https://www.lcsc.com/product-detail/span-style-background-color-ff0-Tantalum-span-Capacitors_KEMET-T520B337M006ATE040_C696806.html
3 | C3 | 1 | Samsung Electro-Mechanics | CL10A106KP8NNNC | 10u | Ceramic Capacitor 10uF 10% 10V X5R | 0603_1608Metric | SMD | LCSC | C19702 | https://www.lcsc.com/product-detail/_Samsung-Electro-Mechanics-_C19702.html
4 | C4 | 1 | YAGEO | CC0402KRX7R9BB103 | 10n | Ceramic Capacitor 10nF 10% 50V X7R | 0402_1005Metric | SMD | LCSC | C60133 | https://www.lcsc.com/product-detail/Multilayer-Ceramic-Capacitors-MLCC-SMD-SMT_YAGEO-CC0402KRX7R9BB103_C60133.html
5 | C5 | 1 | YAGEO | CC0402KRX5R6BB104 | 100n | Ceramic Capacitor 100nF 10% 10V X5R | 0402_1005Metric | SMD | LCSC | C129131 | https://www.lcsc.com/product-detail/Multilayer-Ceramic-Capacitors-MLCC-SMD-SMT_YAGEO-CC0402KRX5R6BB104_C129131.html
6 | C6, C7, C8 | 3 | Samsung Electro-Mechanics | CL21A106KPFNNNE | 10u | Ceramic Capacitor 10uF 10% 10V X5R | 0805_2012Metric | SMD | LCSC | C17024 | https://www.lcsc.com/product-detail/_Samsung-Electro-Mechanics-_C17024.html
7 | C9 | 1 | YAGEO | CC0603KRX7R6BB104 | 100n | Ceramic Capacitor 100nF 10% 10V X7R | 0603_1608Metric | SMD | LCSC | C519438 | https://www.lcsc.com/product-detail/_YAGEO-_C519438.html
8 | D1 | 1 | EKINGLUX | E6C0603SEAC1UDA | ORANGE | LED Orange 2V 25mA | 0603_1608Metric | SMD | LCSC | C375450 | https://www.lcsc.com/product-detail/_EKINGLUX-_C375450.html
9 | F1 | 1 | RUILON | SMD0805P075TF | 0.75A | Resettable Fuses 6V 750mA 40A 1.5A | 0805_2012Metric | SMD | LCSC | C20979 | https://www.lcsc.com/product-detail/Resettable-Fuses_RUILON-Shenzhen-Ruilongyuan-Elec-SMD0805P075TF_C20979.html
10 | FB1 | 1 | TDK | MMZ1608B601CTAH0 | MMZ1608B601CTAH0 | Ferrite Beads 400mΩ ±25% 600Ω@100MHz | 0603_1608Metric | SMD | LCSC | C97120 | https://www.lcsc.com/product-detail/Ferrite-Beads_TDK-MMZ1608B601CTAH0_C97120.html
12 | J1 | 1 | XKB Connectivity | U262-161N-4BVC11 | U262-161N-4BVC11 | USB-C Receptacle | XKB_U262-16XN-4BVC11 | SMD | LCSC | C319148 | https://www.lcsc.com/product-detail/USB-Connectors_XKB-Connectivity-U262-161N-4BVC11_C319148.html
13 | J2 | 1 | HCTL | PZ254-1-08-W-8.5 | PinHeader_1x08_P2.54mm_Horizontal | PinHeader 1x08 Pitch 2.54mm Horizontal | PinHeader_1x08_P2.54mm_Horizontal | THT | LCSC | C2894950 | https://www.lcsc.com/product-detail/span-style-background-color-ff0-Pin-span-Headers_HCTL-PZ254-1-08-W-8-5_C2894950.html
14 | J3, J4 | 2 | XFCN | PZ254R-11-02P | PinHeader_1x02_P2.54mm_Horizontal | PinHeader 1x02 Pitch 2.54mm Horizontal | PinHeader_1x02_P2.54mm_Horizontal | THT | LCSC | C492410 | https://www.lcsc.com/product-detail/span-style-background-color-ff0-Pin-span-Headers_XFCN-PZ254R-11-02P_C492410.html
15 | Q1 | 1 | Alpha & Omega Semicon | AO3407A | AO3407A | MOSFET P Channel 30V 4.3A 48mΩ@10V,4.3A 1.4W | SOT-23 | SMD | LCSC | C15155 | https://www.lcsc.com/product-detail/MOSFETs_Alpha-Omega-Semicon-AO3407A_C15155.html
16 | R1, R8 | 2 | UNI-ROYAL(Uniroyal Elec) | 0603WAF1002T5E | 10K | Resistor 10K 1% 100mW | 0603_1608Metric | SMD | LCSC | C25804 | https://www.lcsc.com/product-detail/Chip-span-style-background-color-ff0-Resistor-span-Surface-Mount_UNI-ROYAL-Uniroyal-Elec-0603WAF1002T5E_C25804.html
17 | R2 | 1 | UNI-ROYAL(Uniroyal Elec) | 0603WAF5101T5E | 5.1K | Resistor 5.1K 1% 100mW | 0603_1608Metric | SMD | LCSC | C23186 | https://www.lcsc.com/product-detail/Chip-span-style-background-color-ff0-Resistor-span-Surface-Mount_UNI-ROYAL-Uniroyal-Elec-0603WAF5101T5E_C23186.html
18 | R3 | 1 | UNI-ROYAL(Uniroyal Elec) | 0603WAF2001T5E | 2K | Resistor 2K 1% 100mW | 0603_1608Metric | SMD | LCSC | C22975 | https://www.lcsc.com/product-detail/Chip-span-style-background-color-ff0-Resistor-span-Surface-Mount_UNI-ROYAL-Uniroyal-Elec-0603WAF2001T5E_C22975.html
19 | R4, R7 | 2 | UNI-ROYAL(Uniroyal Elec) | 0603WAF1001T5E | 1K | Resistor 1K 1% 100mW | 0603_1608Metric | SMD | LCSC | C21190 | https://www.lcsc.com/product-detail/Chip-span-style-background-color-ff0-Resistor-span-Surface-Mount_UNI-ROYAL-Uniroyal-Elec-0603WAF1001T5E_C21190.html
20 | R5, R6 | 2 | UNI-ROYAL(Uniroyal Elec) | 0402WGF5101TCE | 5.1K | Resistor 5.1K 1% 100mW | 0402_1005Metric | SMD | LCSC | C25905 | https://www.lcsc.com/product-detail/Chip-span-style-background-color-ff0-Resistor-span-Surface-Mount_UNI-ROYAL-Uniroyal-Elec-0402WGF5101TCE_C25905.html
21 | SW1 | 1 | Omron | A6H-4101 | A6H-4101 | DIP Switches SMD 4Bit SPST 24V 25mA | A6H-4101 | SMD | LCSC | C397291 | https://www.lcsc.com/product-detail/DIP-Switches_Omron-Electronics-A6H-4101_C397291.html
22 | SW2, SW3 | 2 | E-Switch | TL3342F160QG | TL3342F160QG | SPST SMD NO 50mA 100MΩ 100000 Times 12V 160gf@±50gf | SW_SPST_TL3342 | SMD | LCSC | C2886898 | https://www.lcsc.com/product-detail/Tactile-Switches_E-Switch-TL3342F160QG_C2886898.html
23 | TP1, TP2, TP3, TP4, TP5, TP6, TP7, TP8, TP9 | 9 | Preci-Dip | 90055-AS | 90055-AS | Contact Spring Loaded SMD Gold | 90055-AS | THT | Digikey | 1212-1855-ND | https://www.digikey.com/en/products/detail/preci-dip/90055-AS/5451878
24 | U1 | 1 | Microchip | MCP73831T-2ACI/OT | MCP73831T-2ACI/OT | Battery Management ICs 1.5A | SOT-23-5 | SMD | LCSC | C424093 | https://www.lcsc.com/product-detail/Battery-Management-ICs_Microchip-Tech-MCP73831T-2ACI-OT_C424093.html
25 | U2 | 1 | STMicroelectronics | USBLC6-2P6 | USBLC6-2P6 | ESD Protection Devices 6V 17V Unidirectional 5.25V | SOT-666 | SMD | LCSC | C15999 | https://www.lcsc.com/product-detail/ESD-Protection-Devices_STMicroelectronics-USBLC6-2P6_C15999.html
26 | U3 | 1 | Torex Semiconductor | XC6220B331MR-G | XC6220B331MR-G | Linear Voltage Regulators (LDO) 1000mA Fixed +3.3V | SOT-23-5 | SMD | LCSC | C86534 | https://www.lcsc.com/product-detail/Linear-Voltage-Regulators-LDO_Torex-Semicon-XC6220B331MR-G_C86534.html
27 | U4 | 1 | WCH | CH340E | CH340E | USB-UART Bridge 2Mbps Transceiver USB 2.0 | MSOP-10_3x3mm_P0.5mm | SMD | LCSC | C99652 | https://www.lcsc.com/product-detail/USB-ICs_WCH-Jiangsu-Qin-Heng-CH340E_C99652.html

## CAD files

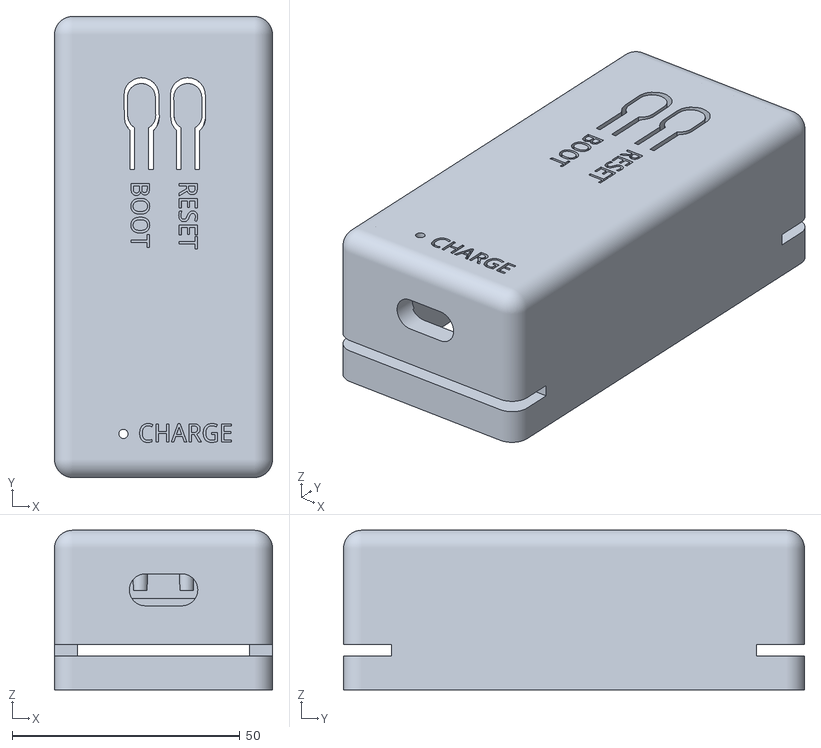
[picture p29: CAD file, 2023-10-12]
hardware/programmer/case/main.stl
47.8 x 101.1 x 35.0

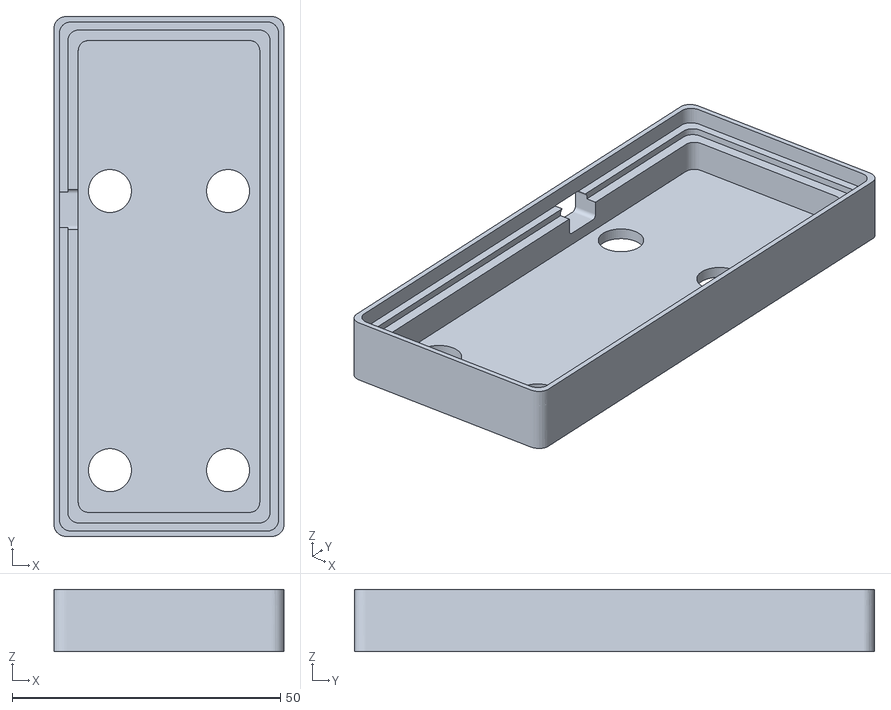
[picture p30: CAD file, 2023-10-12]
hardware/main/case/bottom.stl
42.8 x 96.9 x 11.6

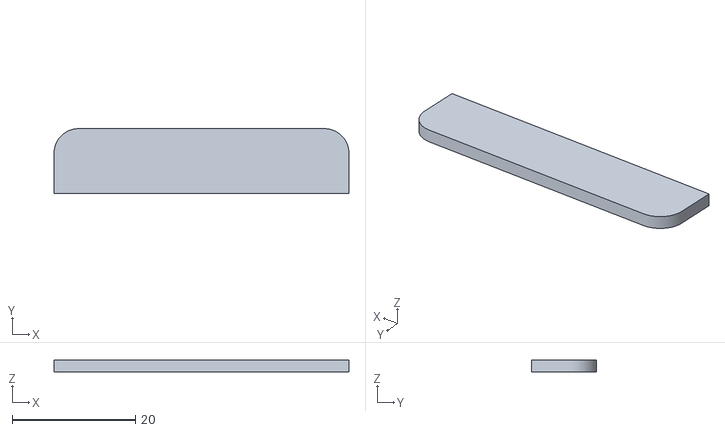
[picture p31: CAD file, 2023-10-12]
hardware/programmer/case/lock.stl
47.8 x 10.5 x 2.00

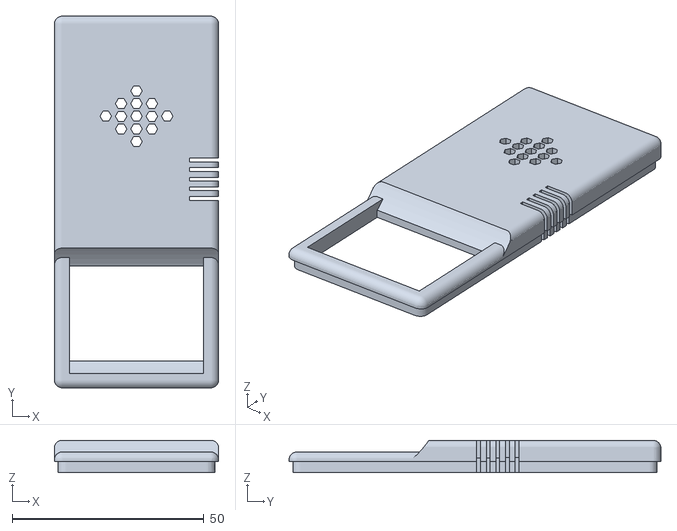
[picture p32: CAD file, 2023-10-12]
hardware/main/case/top.stl
42.8 x 96.9 x 8.46

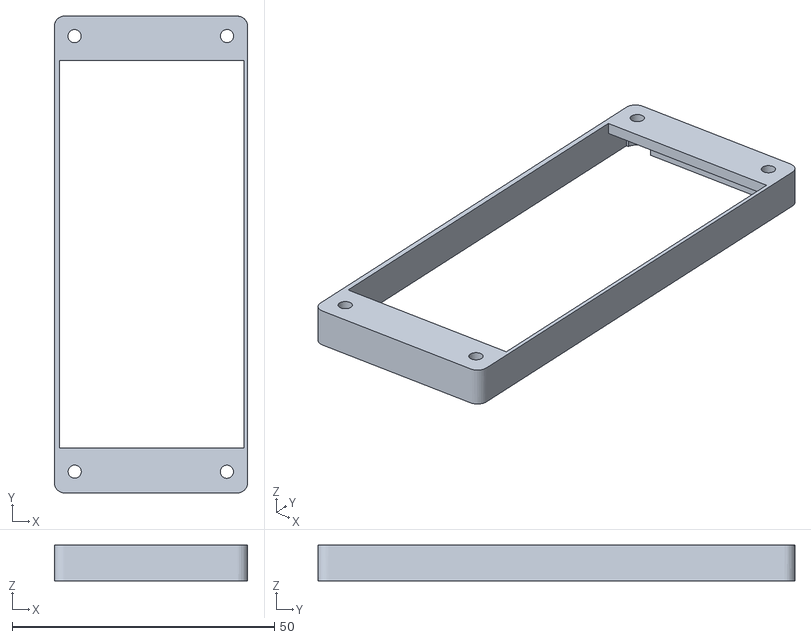
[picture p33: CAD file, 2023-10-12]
hardware/programmer/case/separator.stl
36.8 x 90.9 x 6.86

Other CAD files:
hardware/main/case/bottom_without_qwiic.stl

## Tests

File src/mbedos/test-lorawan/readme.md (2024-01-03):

# BSEC BME688 Test Example

Tested on:

 - Compiler ARMC6
   - With/without sleep trace enabled 
 - [BSEC2 Library](https://www.bosch-sensortec.com/software-tools/software/bme688-software/)

## Acknowledgement
Source code is based on https://github.com/Mircerson/AERQ

## TODO

- [x] Update BSEC library to use the latest version
- [x] Provide BSEC static library
  - `libalgobsec.a` for GCC_ARM
  - `libalgobsec.ar` for ARMC6 ( currently rename the .lib file to .ar from the BSEC library)
  - STM32WL55CC is Cortex-M4
- [x] Implement simple AQI reader without proper sleep
- [ ] Rewrite BME688 high-level library
- [ ] Create a different repo for proper AQI reader with sleep

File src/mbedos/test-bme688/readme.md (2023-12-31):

# BSEC BME688 Test Example

Tested on:

 - Compiler ARMC6
   - With/without sleep trace enabled 
 - [BSEC2 Library](https://www.bosch-sensortec.com/software-tools/software/bme688-software/)

## Acknowledgement
Source code is based on https://github.com/boschsensortec/Bosch-BSEC2-Library

## TODO

- [x] Update BSEC library to use the latest version
- [x] Provide BSEC static library
  - `libalgobsec.a` for GCC_ARM
  - `libalgobsec.ar` for ARMC6 ( currently rename the .lib file to .ar from the BSEC library)
  - STM32WL55CC is Cortex-M4
- [x] Implement simple AQI reader without proper sleep
- [x] Rewrite BME688 high-level library
- [x] Implement proper AQI Reader in ULP mode with Deep-Sleep (STOP2)

## Notes

If using RAK3172, then set the following under `mbed_app.json`
  
    "RAK3172": {
        "stm32wl-lora-driver.rf_switch_config": 2,
        "stm32wl-lora-driver.crystal_select" : 0
    }

If using RAK3172-T ( with TCXO ), then set the following under `mbed_app.json`

    "RAK3172": {
        "stm32wl-lora-driver.rf_switch_config": 2,
        "stm32wl-lora-driver.crystal_select" : 1
    }

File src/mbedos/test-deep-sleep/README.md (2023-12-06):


# Example LoRaWAN application for Mbed-OS

This is an example application based on `Mbed-OS` LoRaWAN protocol APIs. The Mbed-OS LoRaWAN stack implementation is compliant with LoRaWAN v1.0.2 specification.  See this [link](https://os.mbed.com/blog/entry/Introducing-LoRaWAN-11-support/) for information on support for other LoRaWAN spec versions. This application can work with any Network Server if you have correct credentials for the said Network Server. 

## Getting Started

### Supported Hardware
[Mbed Enabled board with an Arduino form factor](https://os.mbed.com/platforms/?q=&Form+Factor=Arduino+Compatible) and one of the following:
- [SX126X shield](https://os.mbed.com/components/SX126xMB2xAS/)
- [SX1276 shield](https://os.mbed.com/components/SX1276MB1xAS/)
- [SX1272 shield](https://os.mbed.com/components/SX1272MB2xAS/) 

OR

Mbed Enabled LoRa MCU:
- STM32WL : [NUCLEO_WL55JC](https://os.mbed.com/platforms/ST-Nucleo-WL55JC/)

OR

[Mbed Enabled LoRa Module](#module-support)

### Mbed OS build tools

#### Mbed CLI 2
Starting with version 6.5, Mbed OS uses Mbed CLI 2. It uses Ninja as a build system, and CMake to generate the build environment and manage the build process in a compiler-independent manner. If you are working with Mbed OS version prior to 6.5 then check the section [Mbed CLI 1](#mbed-cli-1).
1. [Install Mbed CLI 2](https://os.mbed.com/docs/mbed-os/latest/build-tools/install-or-upgrade.html).
1. From the command-line, import the example: `mbed-tools import mbed-os-example-lorawan`
1. Change the current directory to where the project was imported.

#### Mbed CLI 1
1. [Install Mbed CLI 1](https://os.mbed.com/docs/mbed-os/latest/quick-start/offline-with-mbed-cli.html).
1. From the command-line, import the example: `mbed import mbed-os-example-lorawan`
1. Change the current directory to where the project was imported.

### Configuration and radio selection

For LoRa modules supported by Mbed-OS, the pin set is already provided in the `target-overrides` field of the [`mbed_app.json`](./mbed_app.json) file. For more information on supported modules, please refer to the [module support](#module-support) section.

### Add network credentials

Open the file `mbed_app.json` in the root directory of your application. This file contains all the user specific configurations your application and the Mbed OS LoRaWAN stack need. Network credentials are typically provided by LoRa network provider.

#### For OTAA

Please add `Device EUI`, `Application EUI` and `Application Key` needed for Over-the-air-activation(OTAA). For example:

```json
"lora.device-eui": "{ YOUR_DEVICE_EUI }",
"lora.application-eui": "{ YOUR_APPLICATION_EUI }",
"lora.application-key": "{ YOUR_APPLICATION_KEY }"
```

#### For ABP

For Activation-By-Personalization (ABP) connection method, modify the `mbed_app.json` to enable ABP. You can do it by simply turning off OTAA. For example:

```json
"lora.over-the-air-activation": false,
```

In addition to that, you need to provide `Application Session Key`, `Network Session Key` and `Device Address`. For example:

```json
"lora.appskey": "{ YOUR_APPLICATION_SESSION_KEY }",
"lora.nwkskey": "{ YOUR_NETWORK_SESSION_KEY }",
"lora.device-address": " YOUR_DEVICE_ADDRESS_IN_HEX  " 
```

## Configuring the application

The Mbed OS LoRaWAN stack provides a lot of configuration controls to the application through the Mbed OS configuration system. The previous section discusses some of these controls. This section highlights some useful features that you can configure.

### Selecting a PHY

The LoRaWAN protocol is subject to various country specific regulations concerning radio emissions. That's why the Mbed OS LoRaWAN stack provides a `LoRaPHY` class that you can use to implement any region specific PHY layer. Currently, the Mbed OS LoRaWAN stack provides 10 different country specific implementations of `LoRaPHY` class. Selection of a specific PHY layer happens at compile time. By default, the Mbed OS LoRaWAN stack uses `EU 868 MHz` PHY. An example of selecting a PHY can be:

```josn
        "phy": {
            "help": "LoRa PHY region. 0 = EU868 (default), 1 = AS923, 2 = AU915, 3 = CN470, 4 = CN779, 5 = EU433, 6 = IN865, 7 = KR920, 8 = US915, 9 = US915_HYBRID",
            "value": "0"
        },
```

### Duty cycling

LoRaWAN v1.0.2 specifcation is exclusively duty cycle based. This application comes with duty cycle enabled by default. In other words, the Mbed OS LoRaWAN stack enforces duty cycle. The stack keeps track of transmissions on the channels in use and schedules transmissions on channels that become available in the shortest time possible. We recommend you keep duty cycle on for compliance with your country specific regulations. 

However, you can define a timer value in the application, which you can use to perform a periodic uplink when the duty cycle is turned off. Such a setup should be used only for testing or with a large enough timer value. For example:

```json
"target_overrides": {
    "*": {
        "lora.duty-cycle-on": false
    }
}
```

## Module support

Here is a nonexhaustive list of boards and modules that we have tested with the Mbed OS LoRaWAN stack:

- MultiTech mDot (SX1272)
- MultiTech xDot (SX1272)
- LTEK_FF1705 (SX1272)
- Advantech Wise 1510 (SX1276)
- ST B-L072Z-LRWAN1 LoRa®Discovery kit with Murata CMWX1ZZABZ-091 module (SX1276)
- ST NUCLEO-WL55JC with sub-GHz SoC (STM32WL)

Here is a list of boards and modules that have been tested by the community:

- IMST iM880B (SX1272)
- Embedded Planet Agora (SX1276)

## Building and running

1. Connect a USB cable between the USB port on the target and the host computer.
1. Run the following command to build the example project and program the microcontroller flash memory:

    * Mbed CLI 2

    ```bash
    $ mbed-tools compile -m <TARGET> -t <TOOLCHAIN> --flash --sterm --baudrate 115200
    ```

    * Mbed CLI 1

    ```bash
    $ mbed compile -m <TARGET> -t <TOOLCHAIN> --flash --sterm --baudrate 115200
    ```

Your PC may take a few minutes to compile your code.

The binary is located at:

* **Mbed CLI 2** -
  `./cmake_build/<TARGET>/develop/<TOOLCHAIN>/mbed-os-example-lorawan.bin`

* **Mbed CLI 1** - `./BUILD/<TARGET>/<TOOLCHAIN>/mbed-os-example-lorawan.bin`.

You can manually copy the binary to the target, which gets mounted on the host
computer through USB, rather than using the `--flash` option.

You can also open a serial terminal separately, rather than using the `--sterm --baudrate 115200`
option, with the following command:

* Mbed CLI 2
    ```bash
    $ mbed-tools sterm --baudrate 115200
    ```

* Mbed CLI 1
    ```bash
    $ mbed sterm --baudrate 115200
    ```

## Expected output

The serial terminal shows an output similar to:

```
Mbed LoRaWANStack initialized 

 CONFIRMED message retries : 3 

 Adaptive data  rate (ADR) - Enabled 

 Connection - In Progress ...

 Connection - Successful 

 Dummy Sensor Value = 2.1 

 25 bytes scheduled for transmission 
 
 Message Sent to Network Server

```

## [Optional] Adding trace library
To enable Mbed trace, add to your `mbed_app.json` the following fields:

```json
    "target_overrides": {
        "*": {
            "mbed-trace.enable": true
        }
     }
```
The trace is disabled by default to save RAM and reduce main stack usage (see chapter Memory optimization).

**Please note that some targets with small RAM size (e.g. DISCO_L072CZ_LRWAN1 and MTB_MURATA_ABZ) mbed traces cannot be enabled without increasing the default** `"main_stack_size": 1024`**.**

## [Optional] Memory optimization 

Using `Arm CC compiler` instead of `GCC` reduces `3K` of RAM. Currently the application takes about `15K` of static RAM with Arm CC, which spills over for the platforms with `20K` of RAM because you need to leave space, about `5K`, for dynamic allocation. So if you reduce the application stack size, you can barely fit into the 20K platforms.

For example, add the following into `config` section in your `mbed_app.json`:

```
"main_stack_size": {
    "value": 2048
}
```

Essentially you can make the whole application with Mbed LoRaWAN stack in 6K if you drop the RTOS from Mbed OS and use a smaller standard C/C++ library like new-lib-nano. Please find instructions [here](https://os.mbed.com/blog/entry/Reducing-memory-usage-with-a-custom-prin/).

For more information, please follow this [blog post](https://os.mbed.com/blog/entry/Reducing-memory-usage-by-tuning-RTOS-con/).

### License and contributions

The software is provided under Apache-2.0 license. Contributions to this project are accepted under the same license. Please see [contributing.md](CONTRIBUTING.md) for more info.

This project contains code from other projects. The original license text is included in those source files. They must comply with our license guide.

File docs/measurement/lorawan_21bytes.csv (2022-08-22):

Timestamp(ms) | Current(uA)
0 | 3.499
1 | 3.359
2 | 3.293
3 | 3.279
4 | 3.263
5 | 3.271
6 | 3.271
7 | 3.269
8 | 3.275
9 | 3.271
10 | 3.264
11 | 3.268
12 | 3.266
13 | 3.268
14 | 3.276
15 | 3.283
16 | 3.264
17 | 3.275
18 | 3.269
19 | 3.272
20 | 3.271
21 | 3.278
22 | 3.285
23 | 3.280
24 | 3.290
25 | 3.288
26 | 3.279
27 | 3.273
28 | 3.277
29 | 3.280
30 | 3.274
31 | 3.279
32 | 3.279
33 | 3.294
34 | 3.291
35 | 3.292
36 | 3.296
37 | 3.286
38 | 3.284
39 | 3.289
40 | 3.299
41 | 3.299
42 | 3.308
43 | 3.296
44 | 3.303
45 | 3.305
46 | 3.296
47 | 3.308
48 | 3.311
49 | 3.303
50 | 3.296
51 | 3.302
52 | 3.308
53 | 3.301
54 | 3.301
55 | 3.303
56 | 3.296
57 | 3.297
58 | 3.316
59 | 3.315
60 | 3.303
61 | 3.301
62 | 3.298
63 | 3.302
64 | 3.290
65 | 3.290
66 | 3.292
67 | 3.291
68 | 3.303
69 | 3.299
70 | 3.307
71 | 3.297
72 | 3.302
73 | 3.299
74 | 3.298
75 | 3.304
76 | 3.310
77 | 3.308
78 | 3.303
79 | 3.301
80 | 3.298
81 | 3.301
82 | 3.312
83 | 3.296
84 | 3.301
85 | 3.314
86 | 3.308
87 | 3.294
88 | 3.303
89 | 3.311
90 | 3.314
91 | 3.305
92 | 3.309
93 | 3.312
94 | 3.310
95 | 3.313
96 | 3.305
97 | 3.316
98 | 3.316
99 | 3.321
100 | 3.315
101 | 3.320
102 | 3.317
103 | 3.314
104 | 3.315
105 | 3.316
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

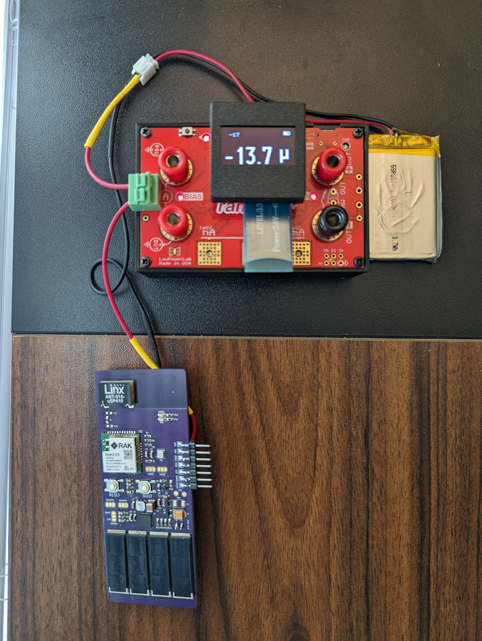
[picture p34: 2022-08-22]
docs/measurement/charge_indirect_very_low_sunlight.jpg

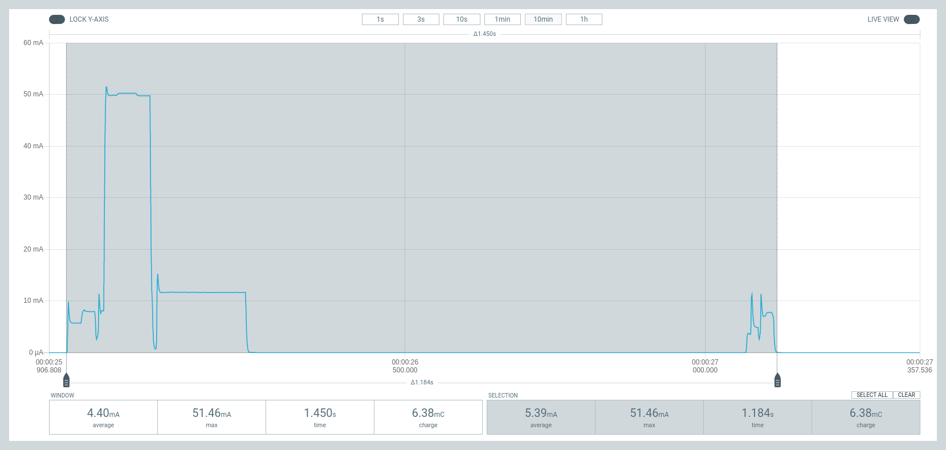
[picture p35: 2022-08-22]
docs/measurement/active.png

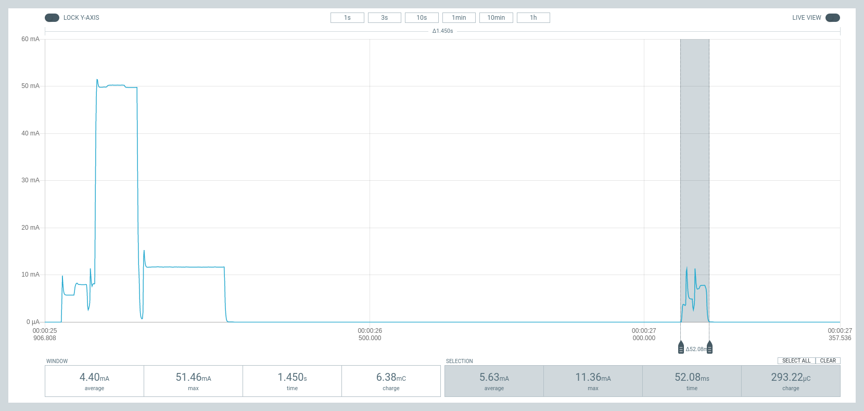
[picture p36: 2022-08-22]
docs/measurement/LoRa_ack.png

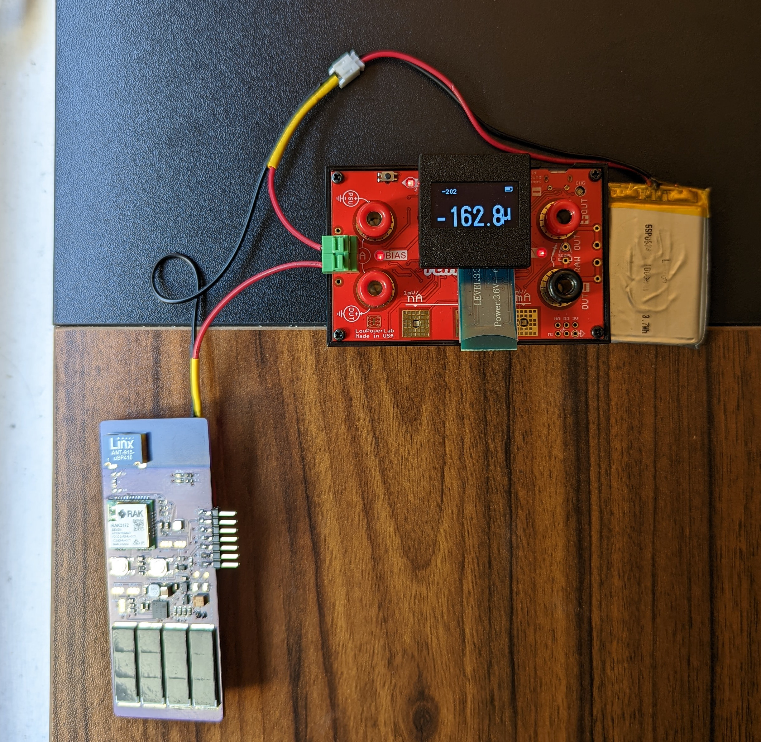
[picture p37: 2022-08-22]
docs/measurement/charge_indirect_low_sunlight.jpg

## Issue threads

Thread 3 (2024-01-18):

PCB assembly

ituri, 2024-01-18:
Hey!

Interesting project! Do you also provide files for the jlpcb pcb assembly? I'm not particularly skilled at soldering small SMD components, so having jlpcb handle that would be greatly appreciated.

Thanks!
ituri

aldwinhermanudin, 2024-01-18:
Thanks!

You could order the device (board+assembly) directly from the manufacturer ( PCBWay ) that I'm using through [here](https://link.teapotlabs.io/bwlr1e-order).

That said, all the necessary file you need for JLCPCB Assembly is available in the repo located at [hardware/main/kicad/production](https://github.com/teapotlaboratories/bwlr1e/tree/main/hardware/main/kicad/production)

Aldwin

ituri, 2024-01-18:
Amazing, didn't know about that before! Thank you!

Closed 2024-01-18.

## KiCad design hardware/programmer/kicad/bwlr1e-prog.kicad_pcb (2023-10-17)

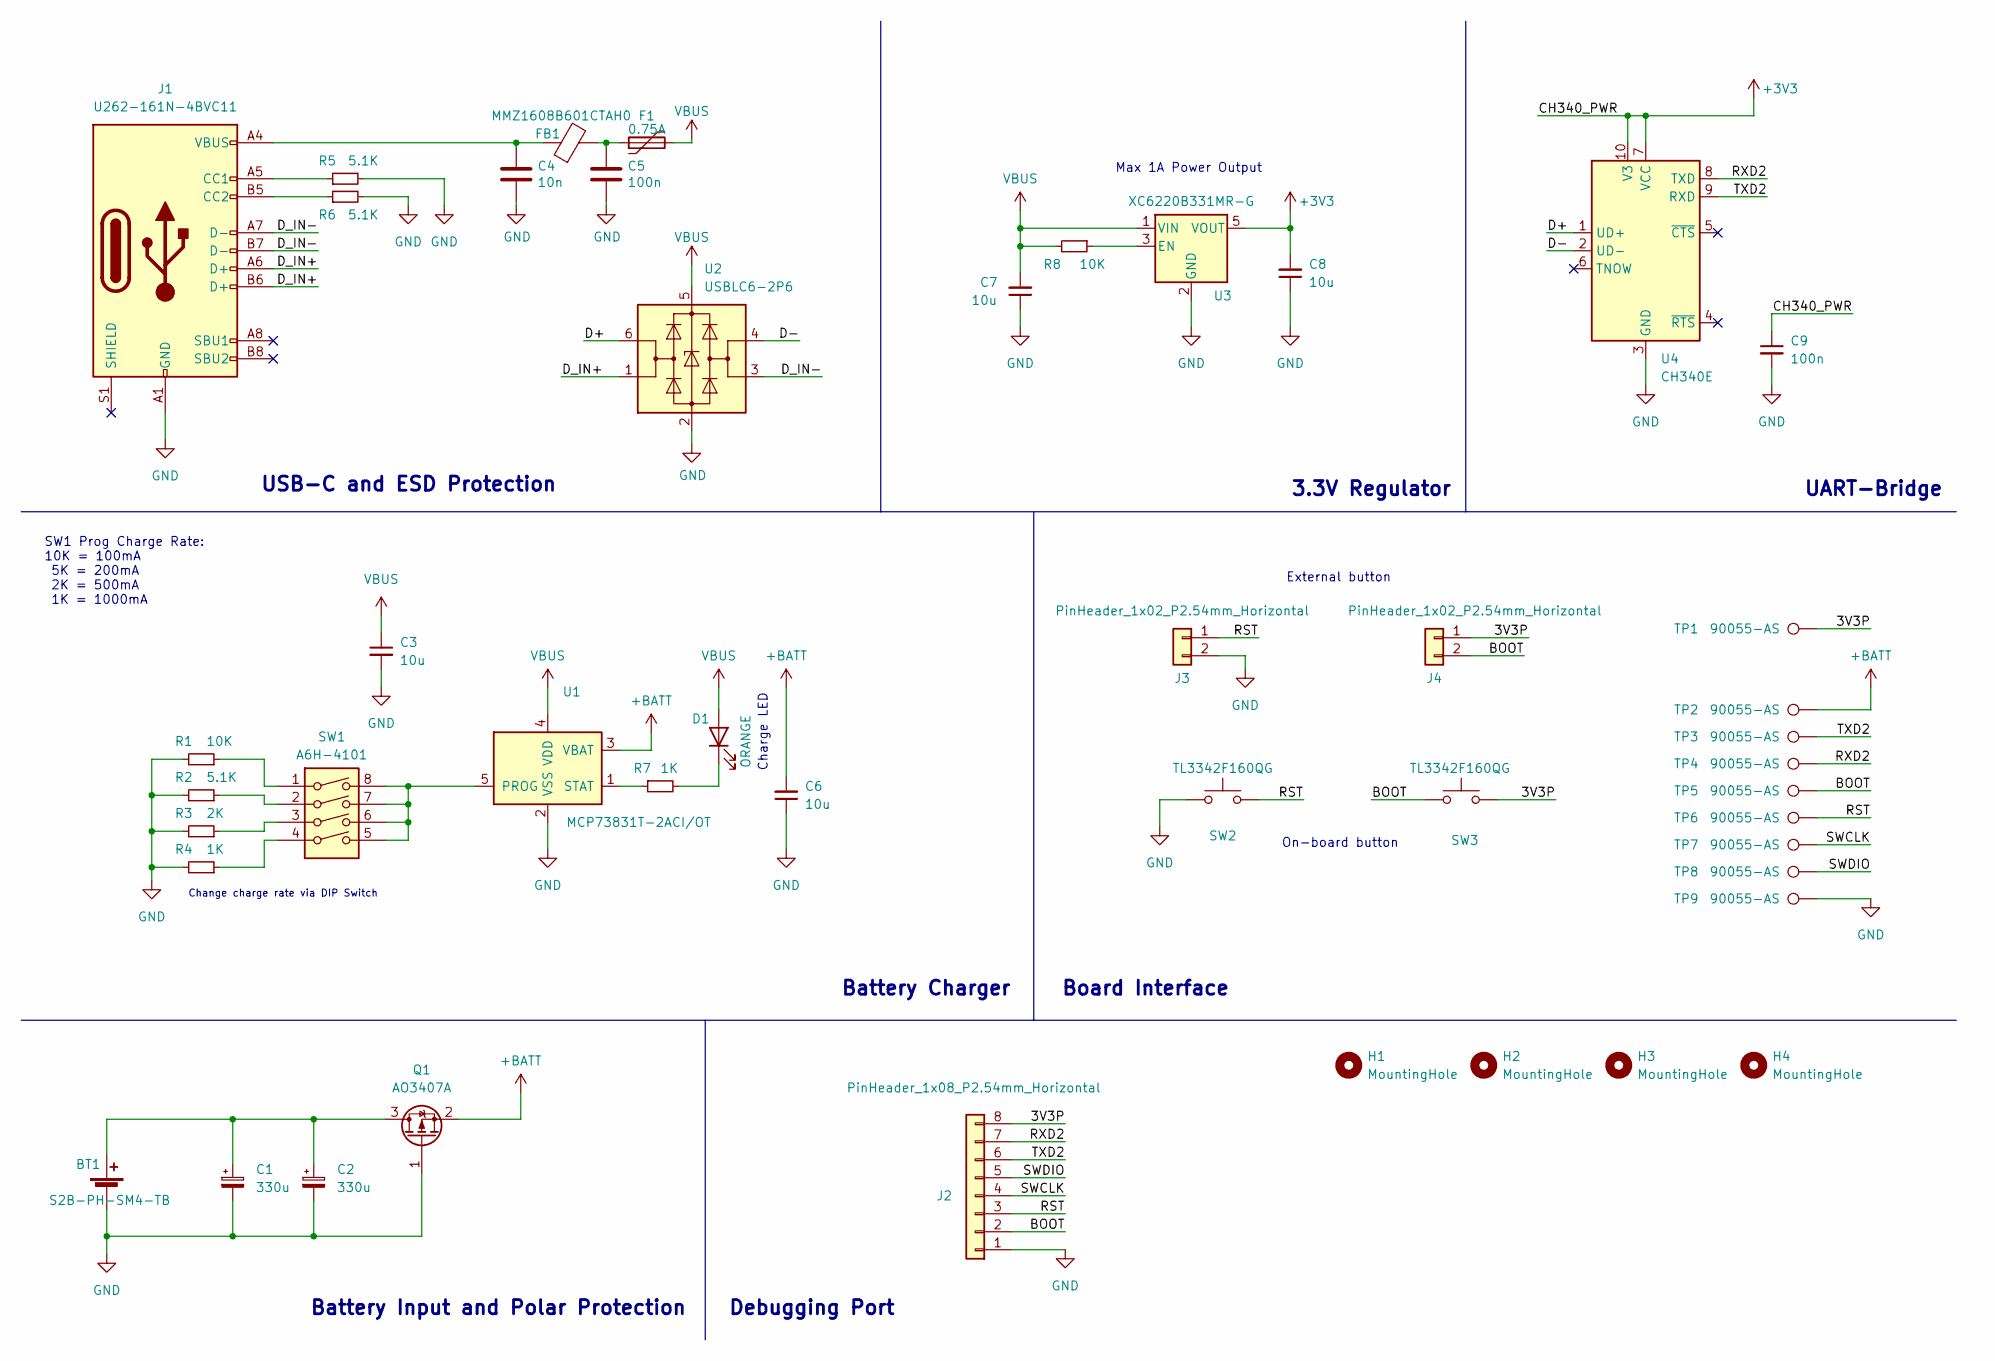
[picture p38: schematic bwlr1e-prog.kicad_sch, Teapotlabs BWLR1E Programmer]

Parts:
BT1: S2B-PH-SM4-TB; JST_PH_S2B-PH-SM4-TB_1x02-1MP_P2.00mm_Horizontal; Part Number S2B-PH-SM4-TB
C1, C2: 330u; CP_EIA-3528-15_AVX-H; Part Number T520B337M006ATE040
C3: 10u; C_0603_1608Metric; Part Description Ceramic Capacitor 10uF 10% 10V X5R
C4: 10n; C_0402_1005Metric; Part Number CC0402KRX7R9BB103
C5: 100n; C_0402_1005Metric; Part Number CC0402KRX5R6BB104
C6, C7, C8: 10u; C_0805_2012Metric; Part Description Ceramic Capacitor 10uF 10% 10V X5R
C9: 100n; C_0603_1608Metric; Part Description Ceramic Capacitor 100nF 10% 10V X7R
D1: ORANGE; LED_0603_1608Metric; Part Description Orange 2V 25mA
F1: 0.75A; Fuse_0805_2012Metric; Part Number SMD0805P075TF
FB1: MMZ1608B601CTAH0; L_0603_1608Metric; Part Number MMZ1608B601CTAH0
H1, H2, H3, H4: MountingHole; MountingHole_2.2mm_M2
J1: U262-161N-4BVC11; USB_C_Receptacle_XKB_U262-16XN-4BVC11; Part Number U262-161N-4BVC11
J2: PinHeader_1x08_P2.54mm_Horizontal
J3, J4: PinHeader_1x02_P2.54mm_Horizontal
Q1: AO3407A; SOT-23; Part Number AO3407A
R1: 10K; R_0603_1608Metric; Part Description Resistor 10K 1% 100mW
R2: 5.1K; R_0603_1608Metric; Part Description Resistor 5.1K 1% 100mW
R3: 2K; R_0603_1608Metric; Part Description Resistor 2K 1% 100mW
R4: 1K; R_0603_1608Metric; Part Description Resistor 1K 1% 100mW
R5, R6: 5.1K; R_0402_1005Metric; Part Description Resistor 5.1K 1% 62.5mW
R7: 1K; R_0603_1608Metric; Part Description Resistor 1k 5% 100mW
R8: 10K; R_0603_1608Metric; Part Description Resistor 10k 5% 100mW
SW1: A6H-4101; SW_DIP_SPSTx04_Slide_Omron_A6H-4101_W6.15mm_P1.27mm; Part Number A6H-4101
SW2, SW3: TL3342F160QG; SW_SPST_TL3342; Part Number TL3342F160QG
TP1, TP2, TP3, TP4, TP5, TP6, TP7, TP8, TP9: 90055-AS; Part Number 90055-AS
U1: MCP73831T-2ACI/OT; SOT-23-5; Part Number MCP73831T-2ACI/OT
U2: USBLC6-2P6; SOT-666; Part Number USBLC6-2P6
U3: XC6220B331MR-G; SOT-23-5; Part Number XC6220B331MR-G
U4: CH340E; MSOP-10_3x3mm_P0.5mm; Part Number CH340E

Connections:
+3V3: C8.2, C9.1, U3.5 (VOUT), U4.7 (VCC), U4.10 (V3)
+BATT: C6.2, Q1.2 (S), TP2.1, U1.3 (VBAT)
/3V3P: J2.8, J4.1, SW3.2, TP1.1
/BOOT: J2.2, J4.2, SW3.1, TP5.1
/D+: U2.6 (I/O1), U4.1 (UD+)
/D-: U2.4 (I/O2), U4.2 (UD-)
/D_IN+: J1.A6 (D+), J1.B6 (D+), U2.1 (I/O1)
/D_IN-: J1.A7 (D-), J1.B7 (D-), U2.3 (I/O2)
/RST: J2.3, J3.1, SW2.2, TP6.1
/RXD2: J2.7, TP4.1, U4.8 (TXD)
/SWCLK: J2.4, TP7.1
/SWDIO: J2.5, TP8.1
/TXD2: J2.6, TP3.1, U4.9 (RXD)
GND: BT1.2 (-), C1.2, C2.2, C3.2, C4.2, C5.2, C6.1, C7.1, C8.1, C9.2, J1.A1 (GND), J1.A12 (GND), J1.B1 (GND), J1.B12 (GND), J2.1, J3.2, Q1.1 (G), R1.2, R2.2, R3.2, R4.2, R5.2, R6.2, SW2.1, TP9.1, U1.2 (VSS), U2.2 (GND), U3.2 (GND), U4.3 (GND)
unnamed: BT1.1 (+), C1.1, C2.1, Q1.3 (D)
unnamed: C4.1, FB1.1, J1.A4 (VBUS), J1.A9 (VBUS), J1.B4 (VBUS), J1.B9 (VBUS)
unnamed: C5.1, F1.1, FB1.2
unnamed: D1.1 (K), R7.2
unnamed: J1.A5 (CC1), R5.1
unnamed: J1.B5 (CC2), R6.1
unnamed: R1.1, SW1.1
unnamed: R2.1, SW1.2
unnamed: R3.1, SW1.3
unnamed: R4.1, SW1.4
unnamed: SW1.5, SW1.6, SW1.7, SW1.8, U1.5 (PROG)
unnamed: R7.1, U1.1 (STAT)
unnamed: R8.1, U3.3 (EN)
VBUS: C3.1, C7.2, D1.2 (A), F1.2, R8.2, U1.4 (VDD), U2.5 (VBUS), U3.1 (VIN)

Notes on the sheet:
SW1 Prog Charge Rate: 10K = 100mA 5K = 200mA 2K = 500mA 1K = 1000mA
External button
Max 1A Power Output
On-board button
Debugging Port
Charge LED
UART-Bridge
Change charge rate via DIP Switch
Battery Input and Polar Protection
USB-C and ESD Protection
Battery Charger
3.3V Regulator
Board Interface

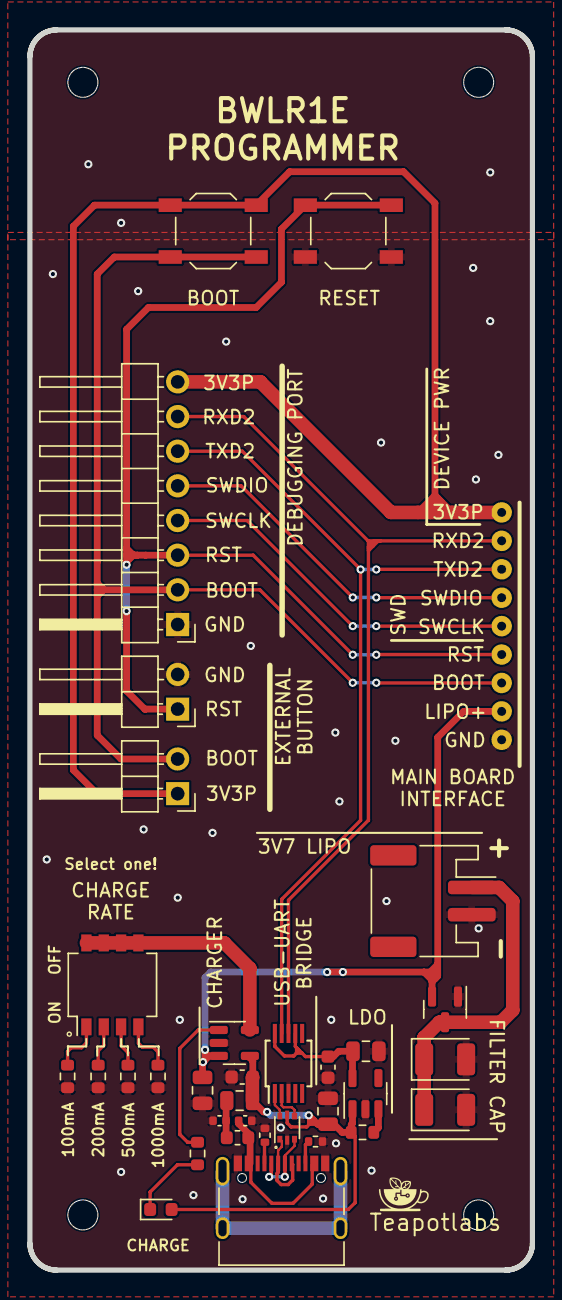
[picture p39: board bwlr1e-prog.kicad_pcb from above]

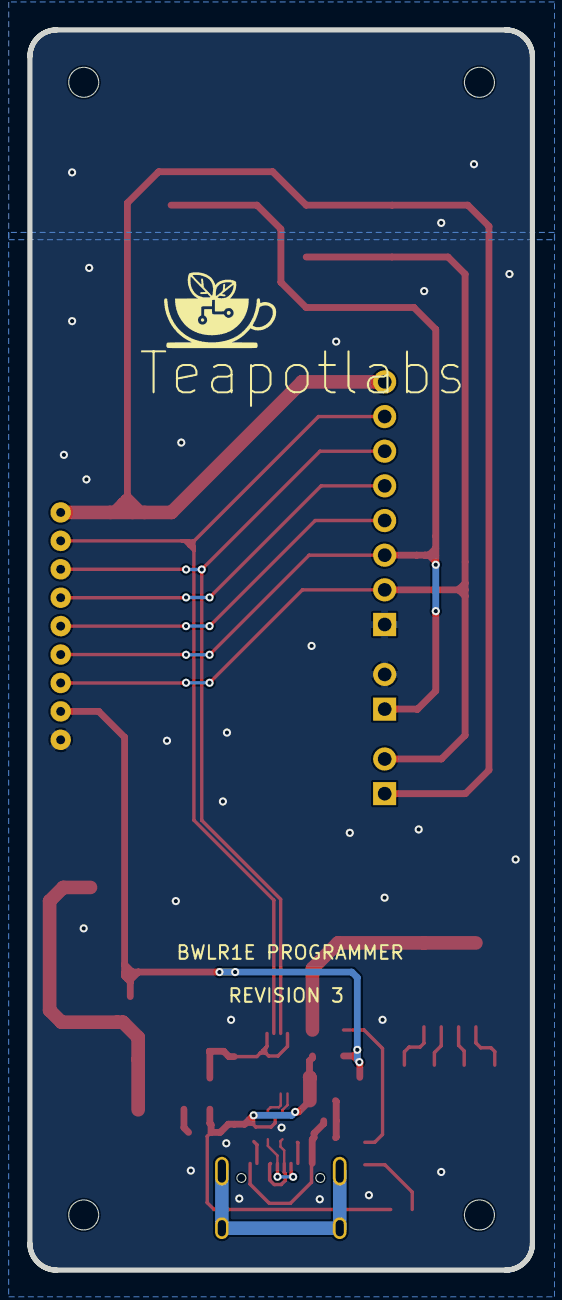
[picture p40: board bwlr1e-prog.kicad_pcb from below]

Board: 2 copper layers, 36.8 x 90.9 mm, 46 parts (9 on the bottom side), 28 nets.

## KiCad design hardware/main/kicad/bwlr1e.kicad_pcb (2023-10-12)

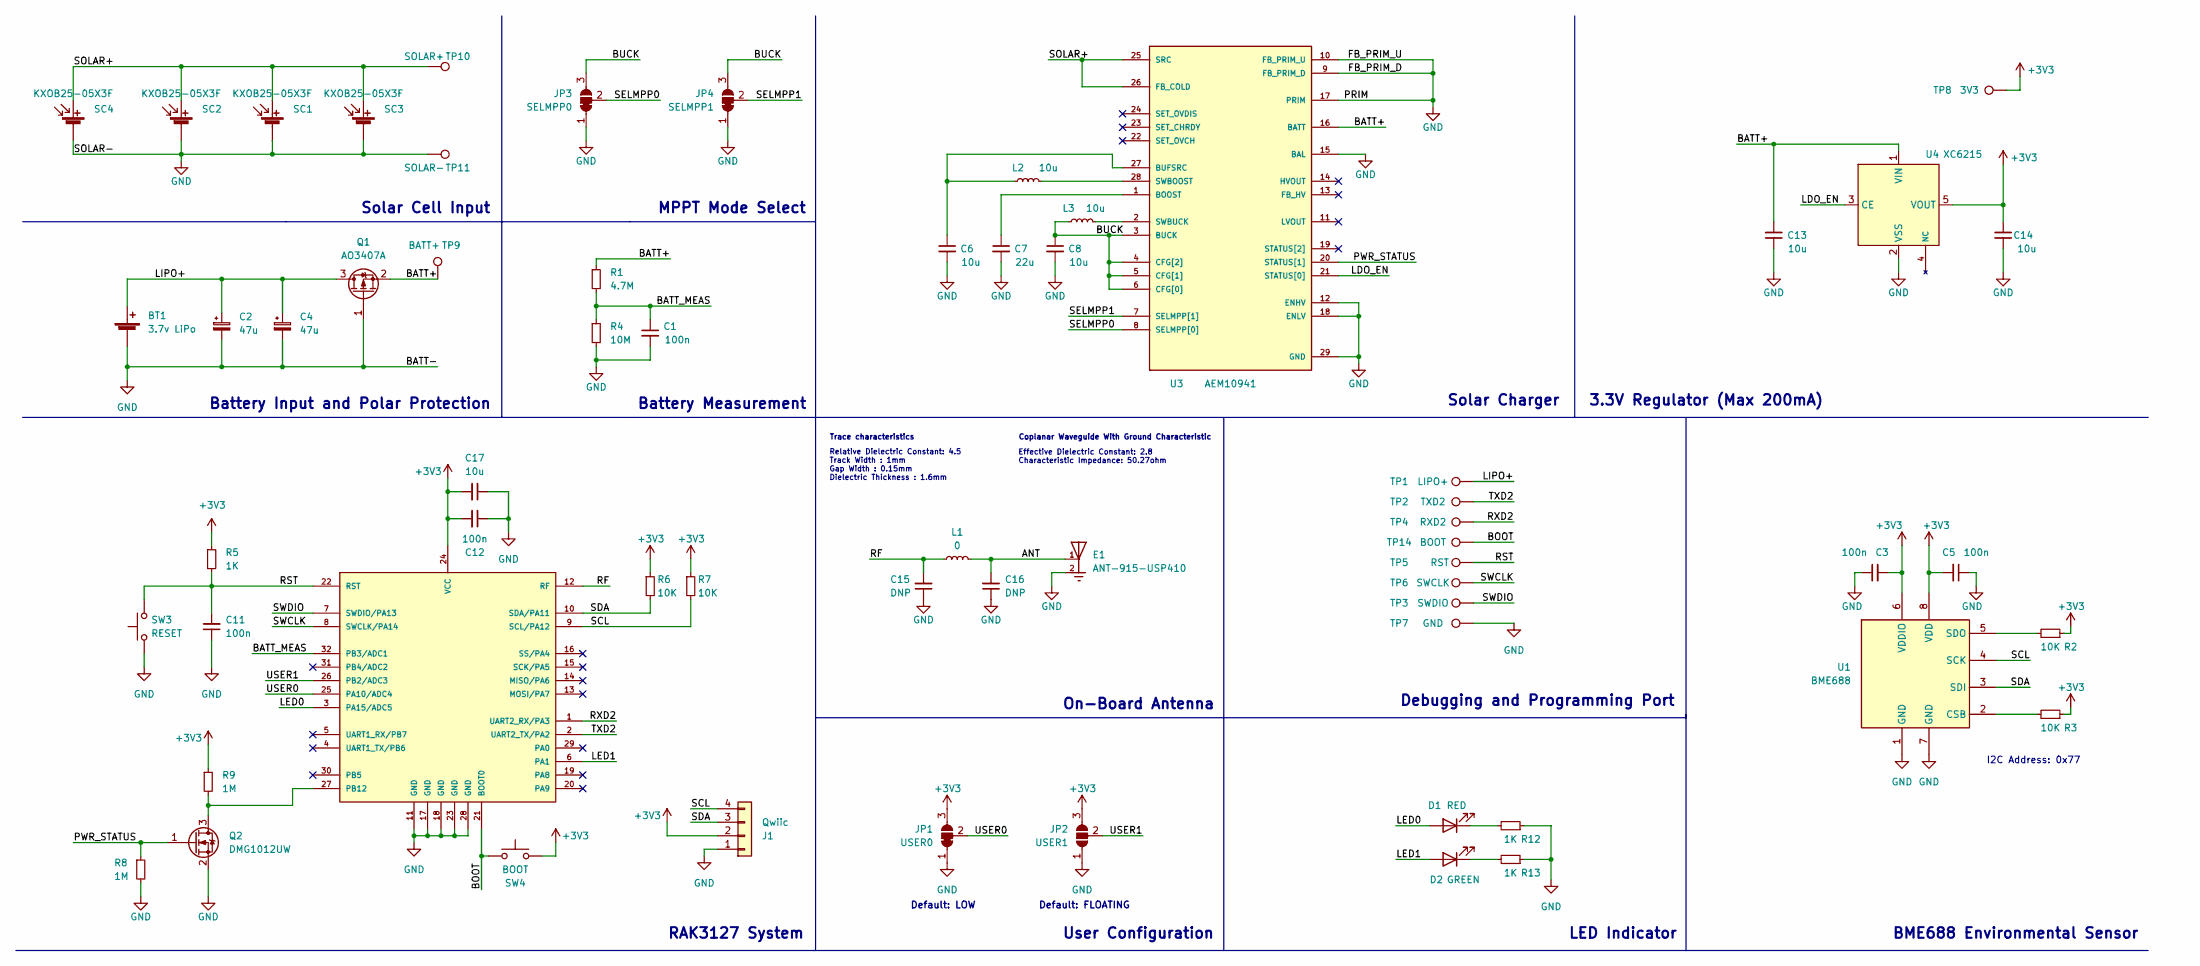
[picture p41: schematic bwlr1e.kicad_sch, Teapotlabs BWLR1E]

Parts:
BT1: 3.7v LiPo; JST_PH_S2B-PH-SM4-TB_1x02-1MP_P2.00mm_Horizontal; Part Number S2B-PH-SM4-TB
C1, C3, C5, C11, C12: 100n; C_0603_1608Metric_Pad1.08x0.95mm_HandSolder; Part Description Ceramic Capacitor 100nF 10% 10V X7R
C2, C4: 47u; CP_EIA-3528-15_AVX-H_Pad1.50x2.35mm_HandSolder; Part Number TPSB476K010R0350
C6: 10u; C_0603_1608Metric; Part Description Ceramic Capacitor 10uF 10% 10V X5R
C7: 22u; C_0603_1608Metric_Pad1.08x0.95mm_HandSolder; Part Description Ceramic Capacitor 22uF 20% 10V X5R
C8, C13, C14, C17: 10u; C_0603_1608Metric_Pad1.08x0.95mm_HandSolder; Part Description Ceramic Capacitor 10uF 10% 10V X5R
C15, C16: DNP; C_0603_1608Metric_Pad1.08x0.95mm_HandSolder
D1: RED; LED_0603_1608Metric_Pad1.05x0.95mm_HandSolder; Part Description Red 2V 20mA
D2: GREEN; LED_0603_1608Metric_Pad1.05x0.95mm_HandSolder; Part Description Green 2V 20mA
E1: ANT-915-USP410; XDCR_ANT-915-USP410; Part Number ANT-915-USP410
J1: Qwiic; JST_SH_SM04B-SRSS-TB_1x04-1MP_P1.00mm_Horizontal; Part Number SM04B-SRSS-TB
JP1: USER0; SolderJumper-3_P1.3mm_Bridged12_RoundedPad1.0x1.5mm
JP2: USER1; SolderJumper-3_P1.3mm_Open_RoundedPad1.0x1.5mm
JP3: SELMPP0; SolderJumper-3_P1.3mm_Bridged12_RoundedPad1.0x1.5mm_NumberL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
JP4: SELMPP1; SolderJumper-3_P1.3mm_Bridged12_RoundedPad1.0x1.5mm_NumberL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
L1: 0; L_0603_1608Metric_Pad1.05x0.95mm_HandSolder
L2: 10u; IND_LPS4012-103MRB; Part Description Power Inductor 10uH 20% 1.1A
L3: 10u; L_0603_1608Metric_Pad1.05x0.95mm_HandSolder; Part Description Power Inductor 10uH 20% 90mA
Q1: AO3407A; SOT-23; Part Number AO3407A
Q2: DMG1012UW; SOT-323_SC-70; Part Number DMG1012UW
R1: 4.7M; R_0603_1608Metric_Pad0.98x0.95mm_HandSolder; Part Description Resistor 4.7M 1% 100mW
R2, R3, R6, R7: 10K; R_0603_1608Metric_Pad0.98x0.95mm_HandSolder; Part Description Resistor 10K 5% 100mW
R4: 10M; R_0603_1608Metric_Pad0.98x0.95mm_HandSolder; Part Description Resistor 10M 1% 100mW
R5, R12, R13: 1K; R_0603_1608Metric_Pad0.98x0.95mm_HandSolder; Part Description Resistor 1K 5% 100mW
R8, R9: 1M; R_0603_1608Metric_Pad0.98x0.95mm_HandSolder; Part Description Resistor 1M 5% 100mW
SC1, SC2, SC3, SC4: KXOB25-05X3F; Part Number KXOB25-05X3F
SW3: RESET; SW_SPST_TL3342; Part Number TL3342F160QG
SW4: BOOT; SW_SPST_TL3342; Part Number TL3342F160QG
TP1: LIPO+; TestPoint_Pad_D1.0mm
TP2: TXD2; TestPoint_Pad_D1.0mm
TP3: SWDIO; TestPoint_Pad_D1.0mm
TP4: RXD2; TestPoint_Pad_D1.0mm
TP5: RST; TestPoint_Pad_D1.0mm
TP6: SWCLK; TestPoint_Pad_D1.0mm
TP7: GND; TestPoint_Pad_D1.0mm
TP8: 3V3; TestPoint_Pad_D1.0mm
TP9: BATT+; TestPoint_Pad_D1.0mm
TP10: SOLAR+; TestPoint_Pad_D1.5mm
TP11: SOLAR-; TestPoint_Pad_D1.5mm
TP14: BOOT; TestPoint_Pad_D1.0mm
U1: BME688; BME680-PSON80P300X300X100-8N; Part Number BME688
U2: RAK3172-T; RAK3172; Part Number 309054
U3: AEM10941; QFN-28-1EP_5x5mm_P0.5mm_EP3.35x3.35mm; Part Number AEM10941-QFN
U4: XC6215; SOT-23-5; Part Number XC6215B332MR-G

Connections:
+3V3: C3.2, C5.2, C12.2, C14.1, C17.2, J1.2, JP1.3 (B), JP2.3 (B), R2.1, R3.1, R5.1, R6.1, R7.1, R9.1, SW4.2, TP8.1, U1.6 (VDDIO), U1.8 (VDD), U2.24 (VCC), U4.5 (VOUT)
/ANT: C16.2, E1.1, L1.2
/BATT+: C13.1, Q1.2 (S), R1.1, TP9.1, U3.16 (BATT), U4.1 (VIN)
/BATT_MEAS: C1.1, R1.2, R4.1, U2.32 (PB3/ADC1)
/BOOT: SW4.1, TP14.1, U2.21 (BOOT0)
/BUCK: C8.1, JP3.3 (B), JP4.3 (B), L3.1, U3.3 (BUCK), U3.4 (CFG[2]), U3.5 (CFG[1]), U3.6 (CFG[0])
/LDO_EN: U3.21 (STATUS[0]), U4.3 (CE)
/LED0: D1.2 (A), U2.3 (PA15/ADC5)
/LED1: D2.2 (A), U2.6 (PA1)
/LIPO+: BT1.1 (+), C2.1, C4.1, Q1.3 (D), TP1.1
/PWR_STATUS: Q2.1 (G), R8.1, U3.20 (STATUS[1])
/RF: C15.2, L1.1, U2.12 (RF)
/RST: C11.2, R5.2, SW3.2, TP5.1, U2.22 (RST)
/RXD2: TP4.1, U2.1 (UART2_RX/PA3)
/SCL: J1.4, R7.2, U1.4 (SCK), U2.9 (SCL/PA12)
/SDA: J1.3, R6.2, U1.3 (SDI), U2.10 (SDA/PA11)
/SELMPP0: JP3.2 (C), U3.8 (SELMPP[0])
/SELMPP1: JP4.2 (C), U3.7 (SELMPP[1])
/SOLAR+: SC1.1 (+), SC2.1 (+), SC3.1 (+), SC4.1 (+), TP10.1, U3.25 (SRC), U3.26 (FB_COLD)
/SWCLK: TP6.1, U2.8 (SWCLK/PA14)
/SWDIO: TP3.1, U2.7 (SWDIO/PA13)
/TXD2: TP2.1, U2.2 (UART2_TX/PA2)
/USER0: JP1.2 (C), U2.25 (PA10/ADC4)
/USER1: JP2.2 (C), U2.26 (PB2/ADC3)
GND: BT1.2 (-), C1.2, C2.2, C3.1, C4.2, C5.1, C6.2, C7.2, C8.2, C11.1, C12.1, C13.2, C14.2, C15.1, C16.1, C17.1, E1.2, J1.1, JP1.1 (A), JP2.1 (A), JP3.1 (A), JP4.1 (A), Q1.1 (G), Q2.2 (S), R4.2, R8.2, R12.1, R13.1, SC1.2 (-), SC2.2 (-), SC3.2 (-), SC4.2 (-), SW3.1, TP7.1, TP11.1, U1.1 (GND), U1.7 (GND), U2.11 (GND), U2.17 (GND), U2.18 (GND), U2.23 (GND), U2.28 (GND), U3.9 (FB_PRIM_D), U3.10 (FB_PRIM_U), U3.12 (ENHV), U3.15 (BAL), U3.17 (PRIM), U3.18 (ENLV), U3.29 (GND), U4.2 (VSS)
unnamed: D1.1 (K), R12.2
unnamed: D2.1 (K), R13.2
unnamed: Q2.3 (D), R9.2, U2.27 (PB12)
unnamed: R3.2, U1.2 (CSB)
unnamed: R2.2, U1.5 (SDO)
unnamed: C7.1, U3.1 (BOOST)
unnamed: C6.1, L2.1, U3.27 (BUFSRC)
unnamed: L2.2, U3.28 (SWBOOST)
unnamed: L3.2, U3.2 (SWBUCK)

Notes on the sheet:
On-Board Antenna
Effective Dielectric Constant: 2.8 Characteristic Impedance: 50.27ohm
RAK3127 System
MPPT Mode Select
BME688 Environmental Sensor
LED Indicator
Coplanar Waveguide With Ground Characteristic
Solar Cell Input
Solar Charger
Default: FLOATING
Default: LOW
Battery Measurement
Trace characteristics
I2C Address: 0x77
Battery Input and Polar Protection
User Configuration
3.3V Regulator (Max 200mA)
Relative Dielectric Constant: 4.5 Track Width : 1mm Gap Width : 0.15mm Dielectric Thickness : 1.6mm
Debugging and Programming Port

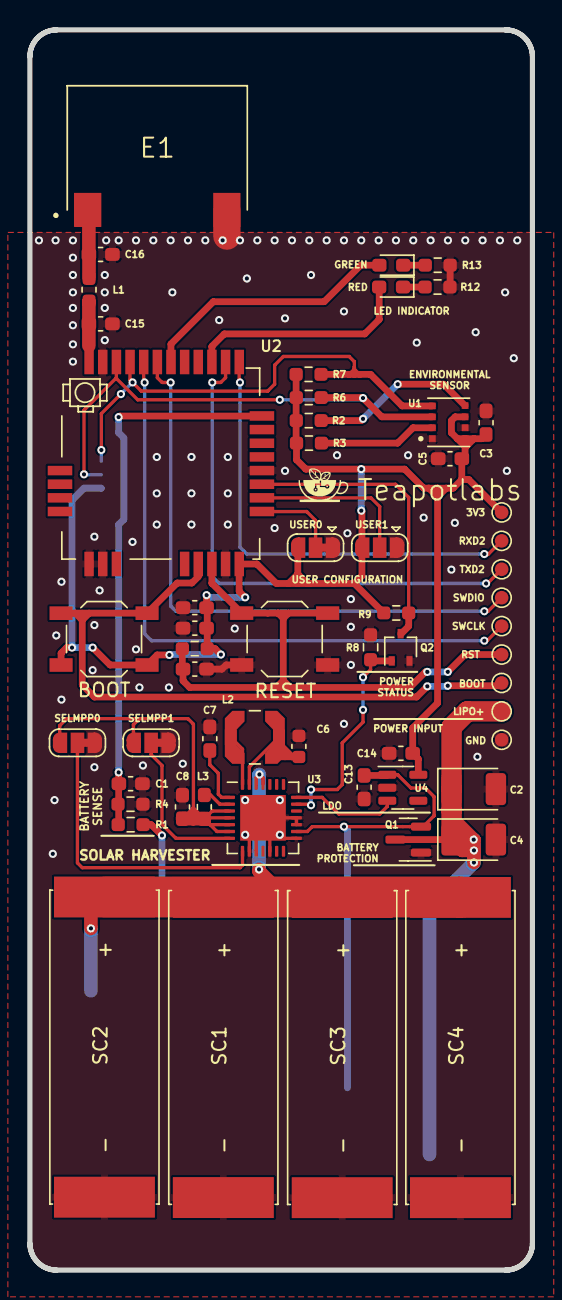
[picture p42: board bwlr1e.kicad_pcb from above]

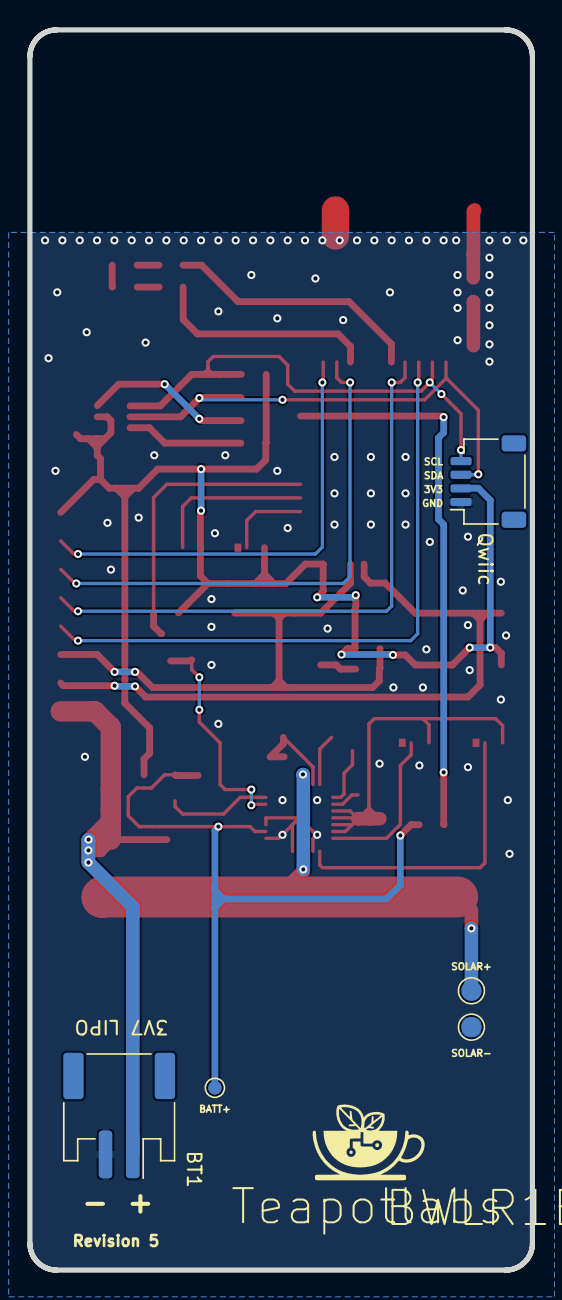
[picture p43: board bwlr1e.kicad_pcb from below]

Board: 2 copper layers, 36.8 x 90.9 mm, 62 parts (5 on the bottom side), 34 nets.

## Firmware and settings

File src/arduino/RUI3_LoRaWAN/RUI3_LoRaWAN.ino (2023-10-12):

/***
 *  This example shows LoRaWan protocol joining the network in OTAA mode, class A, region EU868.
 *  Device will send uplink every 20 seconds.
***/

#define OTAA_PERIOD   (20000)
/*************************************

   LoRaWAN band setting:
     RAK_REGION_EU433
     RAK_REGION_CN470
     RAK_REGION_RU864
     RAK_REGION_IN865
     RAK_REGION_EU868
     RAK_REGION_US915
     RAK_REGION_AU915
     RAK_REGION_KR920
     RAK_REGION_AS923

 *************************************/

#define OTAA_BAND     (RAK_REGION_US915)
#define OTAA_DEVEUI   {0xAC, 0x1F, 0x09, 0xFF, 0xFE, 0x0E, 0x3A, 0x30} // AC1F09FFFE0E3A30
#define OTAA_APPEUI   {0x0E, 0x0D, 0x0D, 0x01, 0x0E, 0x01, 0x02, 0x0E} // 0E0D0D010E01020E
#define OTAA_APPKEY   {0xb5, 0x12, 0xfb, 0x72, 0xfc, 0x87, 0x20, 0x2a, 0xb3, 0x90, 0xc1, 0xbe, 0x8e, 0x46, 0x99, 0xf6} // b512fb72fc87202ab390c1be8e4699f6

/** Packet buffer for sending */
uint8_t collected_data[64] = { 0 };

void recvCallback(SERVICE_LORA_RECEIVE_T * data)
{
    if (data->BufferSize > 0) {
        Serial.println("Something received!");
        for (int i = 0; i < data->BufferSize; i++) {
            Serial.printf("%x", data->Buffer[i]);
        }
        Serial.print("\r\n");
    }
}

void joinCallback(int32_t status)
{
    Serial.printf("Join status: %d\r\n", status);
}

/*************************************
 * enum type for LoRa Event
    RAK_LORAMAC_STATUS_OK = 0,
    RAK_LORAMAC_STATUS_ERROR,
    RAK_LORAMAC_STATUS_TX_TIMEOUT,
    RAK_LORAMAC_STATUS_RX1_TIMEOUT,
    RAK_LORAMAC_STATUS_RX2_TIMEOUT,
    RAK_LORAMAC_STATUS_RX1_ERROR,
    RAK_LORAMAC_STATUS_RX2_ERROR,
    RAK_LORAMAC_STATUS_JOIN_FAIL,
    RAK_LORAMAC_STATUS_DOWNLINK_REPEATED,
    RAK_LORAMAC_STATUS_TX_DR_PAYLOAD_SIZE_ERROR,
    RAK_LORAMAC_STATUS_DOWNLINK_TOO_MANY_FRAMES_LOSS,
    RAK_LORAMAC_STATUS_ADDRESS_FAIL,
    RAK_LORAMAC_STATUS_MIC_FAIL,
    RAK_LORAMAC_STATUS_MULTICAST_FAIL,
    RAK_LORAMAC_STATUS_BEACON_LOCKED,
    RAK_LORAMAC_STATUS_BEACON_LOST,
    RAK_LORAMAC_STATUS_BEACON_NOT_FOUND,
 *************************************/

void sendCallback(int32_t status)
{
    if (status == RAK_LORAMAC_STATUS_OK) {
        Serial.println("Successfully sent");
    } else {
        Serial.println("Sending failed");
    }
}

void setup()
{
    Serial.begin(115200, RAK_AT_MODE);
    delay(2000);
  
    Serial.println("RAKwireless LoRaWan OTAA Example");
    Serial.println("------------------------------------------------------");
  
    if(api.lorawan.nwm.get() != 1)
    {
        Serial.printf("Set Node device work mode %s\r\n",
            api.lorawan.nwm.set(1) ? "Success" : "Fail");
        api.system.reboot();
    }

    // OTAA Device EUI MSB first
    uint8_t node_device_eui[8] = OTAA_DEVEUI;
    // OTAA Application EUI MSB first
    uint8_t node_app_eui[8] = OTAA_APPEUI;
    // OTAA Application Key MSB first
    uint8_t node_app_key[16] = OTAA_APPKEY;
  
    if (!api.lorawan.appeui.set(node_app_eui, 8)) {
        Serial.printf("LoRaWan OTAA - set application EUI is incorrect! \r\n");
        return;
    }
    if (!api.lorawan.appkey.set(node_app_key, 16)) {
        Serial.printf("LoRaWan OTAA - set application key is incorrect! \r\n");
        return;
    }
    if (!api.lorawan.deui.set(node_device_eui, 8)) {
        Serial.printf("LoRaWan OTAA - set device EUI is incorrect! \r\n");
        return;
    }
  
    if (!api.lorawan.band.set(OTAA_BAND)) {
        Serial.printf("LoRaWan OTAA - set band is incorrect! \r\n");
        return;
    }
    if (!api.lorawan.deviceClass.set(RAK_LORA_CLASS_A)) {
        Serial.printf("LoRaWan OTAA - set device class is incorrect! \r\n");
        return;
    }
    if (!api.lorawan.njm.set(RAK_LORA_OTAA))	// Set the network join mode to OTAA
    {
        Serial.printf("LoRaWan OTAA - set network join mode is incorrect! \r\n");
        return;
    }
    if (!api.lorawan.join())	// Join to Gateway
    {
        Serial.printf("LoRaWan OTAA - join fail! \r\n");
        return;
    }
  
    /** Wait for Join success */
    while (api.lorawan.njs.get() == 0) {
        Serial.print("Wait for LoRaWAN join...");
        api.lorawan.join();
        delay(10000);
    }
  
    if (!api.lorawan.adr.set(true)) {
        Serial.printf("LoRaWan OTAA - set adaptive data rate is incorrect! \r\n");
        return;
    }
    if (!api.lorawan.rety.set(1)) {
        Serial.printf("LoRaWan OTAA - set retry times is incorrect! \r\n");
        return;
    }
    if (!api.lorawan.cfm.set(1)) {
        Serial.printf("LoRaWan OTAA - set confirm mode is incorrect! \r\n");
        return;
    }
  
    /** Check LoRaWan Status*/
    Serial.printf("Duty cycle is %s\r\n", api.lorawan.dcs.get()? "ON" : "OFF");	// Check Duty Cycle status
    Serial.printf("Packet is %s\r\n", api.lorawan.cfm.get()? "CONFIRMED" : "UNCONFIRMED");	// Check Confirm status
    uint8_t assigned_dev_addr[4] = { 0 };
    api.lorawan.daddr.get(assigned_dev_addr, 4);
    Serial.printf("Device Address is %02X%02X%02X%02X\r\n", assigned_dev_addr[0], assigned_dev_addr[1], assigned_dev_addr[2], assigned_dev_addr[3]);	// Check Device Address
    Serial.printf("Uplink period is %ums\r\n", OTAA_PERIOD);
    Serial.println("");
    api.lorawan.registerRecvCallback(recvCallback);
    api.lorawan.registerJoinCallback(joinCallback);
    api.lorawan.registerSendCallback(sendCallback);
}

void uplink_routine()
{
    /** Payload of Uplink */
    uint8_t data_len = 0;
    collected_data[data_len++] = (uint8_t) 't';
    collected_data[data_len++] = (uint8_t) 'e';
    collected_data[data_len++] = (uint8_t) 's';
    collected_data[data_len++] = (uint8_t) 't';
  
    Serial.println("Data Packet:");
    for (int i = 0; i < data_len; i++) {
        Serial.printf("0x%02X ", collected_data[i]);
    }
    Serial.println("");
  
    /** Send the data package */
    if (api.lorawan.send(data_len, (uint8_t *) & collected_data, 2, true, 1)) {
        Serial.println("Sending is requested");
    } else {
        Serial.println("Sending failed");
    }
}

void loop()
{
    static uint64_t last = 0;
    static uint64_t elapsed;
  
    if ((elapsed = millis() - last) > OTAA_PERIOD) {
        uplink_routine();
  
        last = millis();
    }
    //Serial.printf("Try sleep %ums..", OTAA_PERIOD);
    api.system.sleep.all(OTAA_PERIOD);
    //Serial.println("Wakeup..");
}

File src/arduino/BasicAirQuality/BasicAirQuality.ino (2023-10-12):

#include "bsec.h"

#undef LED_BUILTIN
#define LED0          PA15
#define LED1          PA1
#define LED_BUILTIN   LED0

// Helper functions declarations
void checkIaqSensorStatus(void);
void errLeds(void);

// Create an object of the class Bsec
Bsec iaqSensor;

String output;

// Entry point for the example
void setup(void)
{
  /* Initializes the Serial communication */
  Serial.begin(115200);
  delay(1000);
  pinMode(LED_BUILTIN, OUTPUT);
  digitalWrite(LED_BUILTIN, LOW);
  iaqSensor.begin(BME68X_I2C_ADDR_HIGH, Wire);
  output = "\nBSEC library version " + String(iaqSensor.version.major) + "." + String(iaqSensor.version.minor) + "." + String(iaqSensor.version.major_bugfix) + "." + String(iaqSensor.version.minor_bugfix);
  Serial.println(output);
  checkIaqSensorStatus();

  bsec_virtual_sensor_t sensorList[13] = {
    BSEC_OUTPUT_IAQ,
    BSEC_OUTPUT_STATIC_IAQ,
    BSEC_OUTPUT_CO2_EQUIVALENT,
    BSEC_OUTPUT_BREATH_VOC_EQUIVALENT,
    BSEC_OUTPUT_RAW_TEMPERATURE,
    BSEC_OUTPUT_RAW_PRESSURE,
    BSEC_OUTPUT_RAW_HUMIDITY,
    BSEC_OUTPUT_RAW_GAS,
    BSEC_OUTPUT_STABILIZATION_STATUS,
    BSEC_OUTPUT_RUN_IN_STATUS,
    BSEC_OUTPUT_SENSOR_HEAT_COMPENSATED_TEMPERATURE,
    BSEC_OUTPUT_SENSOR_HEAT_COMPENSATED_HUMIDITY,
    BSEC_OUTPUT_GAS_PERCENTAGE
  };

  iaqSensor.updateSubscription(sensorList, 13, BSEC_SAMPLE_RATE_LP);
  checkIaqSensorStatus();

  // Print the header
  output = "Timestamp [ms], IAQ, IAQ accuracy, Static IAQ, CO2 equivalent, breath VOC equivalent, raw temp[°C], pressure [hPa], raw relative humidity [%], gas [Ohm], Stab Status, run in status, comp temp[°C], comp humidity [%], gas percentage";
  Serial.println(output);
}

// Function that is looped forever
void loop(void)
{
  unsigned long time_trigger = millis();
  if (iaqSensor.run()) { // If new data is available
    digitalWrite(LED_BUILTIN, LOW);
    output = String(time_trigger);
    output += ", " + String(iaqSensor.iaq);
    output += ", " + String(iaqSensor.iaqAccuracy);
    output += ", " + String(iaqSensor.staticIaq);
    output += ", " + String(iaqSensor.co2Equivalent);
    output += ", " + String(iaqSensor.breathVocEquivalent);
    output += ", " + String(iaqSensor.rawTemperature);
    output += ", " + String(iaqSensor.pressure);
    output += ", " + String(iaqSensor.rawHumidity);
    output += ", " + String(iaqSensor.gasResistance);
    output += ", " + String(iaqSensor.stabStatus);
    output += ", " + String(iaqSensor.runInStatus);
    output += ", " + String(iaqSensor.temperature);
    output += ", " + String(iaqSensor.humidity);
    output += ", " + String(iaqSensor.gasPercentage);
    Serial.println(output);
    digitalWrite(LED_BUILTIN, HIGH);
  } else {
    checkIaqSensorStatus();
  }
}

// Helper function definitions
void checkIaqSensorStatus(void)
{
  if (iaqSensor.bsecStatus != BSEC_OK) {
    if (iaqSensor.bsecStatus < BSEC_OK) {
      output = "BSEC error code : " + String(iaqSensor.bsecStatus);
      Serial.println(output);
      for (;;)
        errLeds(); /* Halt in case of failure */
    } else {
      output = "BSEC warning code : " + String(iaqSensor.bsecStatus);
      Serial.println(output);
    }
  }

  if (iaqSensor.bme68xStatus != BME68X_OK) {
    if (iaqSensor.bme68xStatus < BME68X_OK) {
      output = "BME68X error code : " + String(iaqSensor.bme68xStatus);
      Serial.println(output);
      for (;;)
        errLeds(); /* Halt in case of failure */
    } else {
      output = "BME68X warning code : " + String(iaqSensor.bme68xStatus);
      Serial.println(output);
    }
  }
}

void errLeds(void)
{
  pinMode(LED_BUILTIN, OUTPUT);
  digitalWrite(LED_BUILTIN, HIGH);
  delay(100);
  digitalWrite(LED_BUILTIN, LOW);
  delay(100);
}

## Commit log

2022-08-04 revision 1
    [bwlr1e.kicad_pcb, bwlr1e.kicad_sch]
2022-08-06 revision 2
    [bwlr1e.kicad_pcb, bwlr1e.kicad_sch]
2022-08-22 add documents directory
    [lorawan_21bytes.csv]
2022-08-22 revision 3
    [bwlr1e.kicad_pcb, bwlr1e.kicad_sch]
2022-08-22 add arduino source code example
2022-08-22 adddesign artifacts
    [bill_of_materials.csv, bottom.stl, bottom_with_programming_port.stl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]
2022-08-22 add kicad library
2022-08-25 update logo
    [bwlr1e.kicad_pcb]
2022-09-03 update footprint and library
    [bwlr1e.kicad_pcb]
2022-09-26 move battery measurement to PB3
    [bwlr1e.kicad_pcb, bwlr1e.kicad_sch]
2022-10-22 change jst type to smt
    [bwlr1e.kicad_pcb, bwlr1e.kicad_sch]
2022-10-22 add revision 4 rc1 gerber.zip
2023-08-09 improve layout and silkscreen info
    [bwlr1e.kicad_pcb, bwlr1e.kicad_sch]
2023-08-09 added qwiic connector
    [bwlr1e.kicad_pcb, bwlr1e.kicad_sch]
2023-08-09 add qwiic silkscreen info
    [bwlr1e.kicad_pcb]
2023-08-09 improve qwiic sda trace
    [bwlr1e.kicad_pcb]
2023-08-11 improve silkscreen graphic and wiring
    [bwlr1e.kicad_pcb, bwlr1e.kicad_sch]
2023-08-11 add gnd vias
    [bwlr1e.kicad_pcb]
2023-08-11 rename value unit of components
    [bwlr1e.kicad_sch]
2023-08-12 fix led polarity and minor wiring changes
    [bwlr1e.kicad_pcb, bwlr1e.kicad_sch]
2023-08-12 change library to project-level and minor changes
    [bwlr1e.kicad_pcb, bwlr1e.kicad_sch]
2023-08-12 small improvement and add production info
    [bwlr1e.kicad_pcb, bwlr1e.kicad_sch]
2023-08-13 update RAK3172 description
    [bwlr1e.kicad_sch]
2023-08-13 minor description changes
    [bwlr1e.kicad_pcb]
2023-08-13 update bill of materials
    [bill_of_materials.csv]
2023-08-13 update solar footprint
    [bwlr1e.kicad_pcb]
2023-08-13 initial production files
    [TeapotlabsBWLR1E_BOM.csv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]
2023-08-18 rotate components
    [TeapotlabsBWLR1E_CPL.csv]
2023-08-18 add production files
    [TeapotlabsBWLR1E_BOM.csv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]
2023-08-18 rotate BT1
    [TeapotlabsBWLR1E_CPL.csv]
2023-09-07 initial programmer
    [bwlr1e-prog.kicad_pcb, bwlr1e-prog.kicad_sch]
2023-09-07 fix filter cap footprint
    [bwlr1e-prog.kicad_pcb, bwlr1e-prog.kicad_sch]
2023-09-07 update page title
    [bwlr1e-prog.kicad_pcb, bwlr1e-prog.kicad_sch]
2023-09-07 fix components value
    [bwlr1e-prog.kicad_sch]
2023-09-07 add usb-c receptacle
    [bwlr1e-prog.kicad_pcb, bwlr1e-prog.kicad_sch]
2023-09-07 fix incorrect resistor desc
    [bwlr1e-prog.kicad_sch]
2023-09-07 rename value
    [bwlr1e-prog.kicad_sch]
2023-09-07 add production file
    [TeapotlabsBWLR1EProgrammer_BOM.csv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]
2023-09-07 change folder structure
    [TeapotlabsBWLR1E_BOM.csv, bwlr1e.kicad_pcb, bwlr1e.kicad_sch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]
2023-09-07 update footprint library
    [bwlr1e-prog.kicad_pcb]
2023-09-09 update component value
    [TeapotlabsBWLR1EProgrammer_BOM.csv, bwlr1e-prog.kicad_sch]
2023-09-09 move batt jst to top and change to rev 2
    [bwlr1e-prog.kicad_pcb, bwlr1e-prog.kicad_sch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]
2023-09-21 improve usb diff pair and change to rev 3
    [bwlr1e-prog.kicad_pcb, bwlr1e-prog.kicad_sch]
2023-09-26 change csrc aem10941 to 10uf
    [TeapotlabsBWLR1E_BOM.csv, bwlr1e.kicad_pcb, bwlr1e.kicad_sch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]
2023-10-02 update 3d model
    [bwlr1e.kicad_pcb]
2023-10-08 add 3d case
    [bottom.stl, bottom_with_programming_port.stl, bottom_without_qwiic.stl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]
2023-10-09 update doc files
    [bill_of_materials.csv]
2023-10-10 update power save
2023-10-17 add marker for pcb blender export
    [bwlr1e-prog.kicad_pcb]
2023-12-16 initial effort to re-implement arduino library
2023-12-22 initial implementation for bsec2 arduino
2023-12-22 add correct timer calls
    [BME688.cpp, main.cpp]
2023-12-31 add correct antenna power switch and crystal configuration

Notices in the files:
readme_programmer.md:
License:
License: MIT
